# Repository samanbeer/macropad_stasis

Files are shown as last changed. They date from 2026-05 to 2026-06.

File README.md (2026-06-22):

# My MacroPad Project

This is custom 3×3 macropad PCB built with KiCad. It runs with Seeed Studio XIAO RP2040 microcontroller, uses Cherry MX switches and t has RGB lights with SK6812 MINI-E LEDs.

## About This Project

I have done PCB design before, but I wanted to do something more hard like adding MCU, RGB LEDs, and a matrix connection. 
I learned key matrix wiring with diodes, level-shifting logic with the 74AHCT125 processor, PCB routing around an MCU and KiCad in general. 
Also I learned a lot from MarkDown syntax.
I will use this for switching apps, custom scripts in some apps like VsCode for pushing new code to github etc...
The routing was pretty easy, just time consuming but I really enjoed making traces.

## Project Structure

- **[KiCAD_project/](KiCAD_project/)** 
  - `KiCAD_project.kicad_pcb` 
  - `KiCAD_project.kicad_sch` 
  - `KiCAD_project.kicad_pro` 
  - **[output/](KiCAD_project/output/)** 
  - **[OPL_Kicad_Library-master/](KiCAD_project/OPL_Kicad_Library-master/)**
  - **[kicad-libraries-master/](KiCAD_project/kicad-libraries-master/)** 
  - **[kicad_care_package/](KiCAD_project/kicad_care_package/)** 
  - **[KiCAD_project-backups/](KiCAD_project/KiCAD_project-backups/)** 

- **[CAD/](CAD/)** 
  - `3d_PCB.step` 
  - `housing.stl` 
  - `pcb_only.stl` 
  - `With-PCB_for-render.stl` 
  - `Seeed Studio XIAO RP2040.stl` 
  - **[blender/](CAD/blender/)** 

- **[KiCAD_project/My macroPad-bom.csv](KiCAD_project/My%20macroPad-bom.csv)** - BOM

## Design images

### Schematic
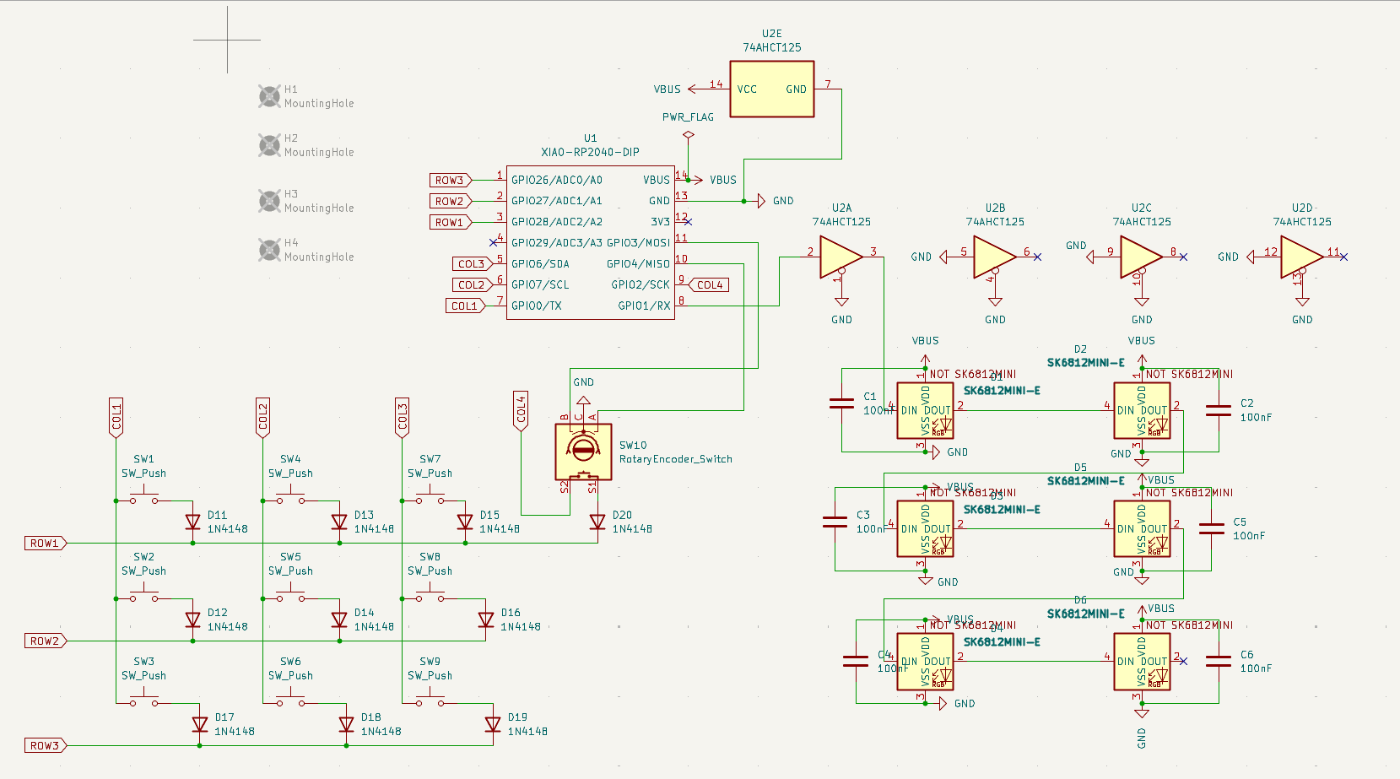
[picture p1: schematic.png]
Schematic


### PCB Layout
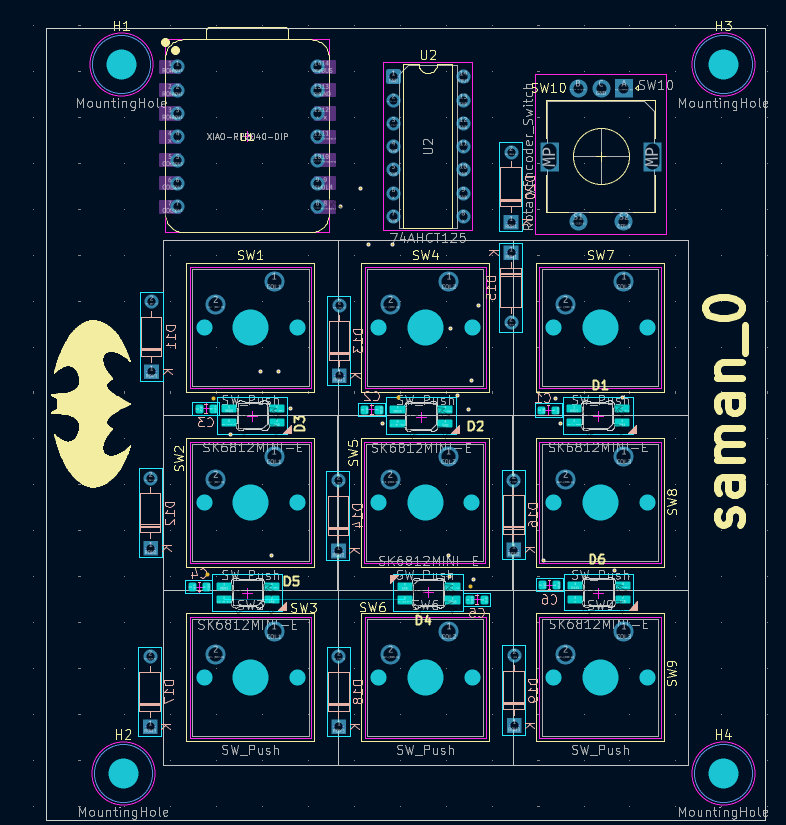
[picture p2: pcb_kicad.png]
PCB Layout


### 3D Renderings

#### Rendered PCB
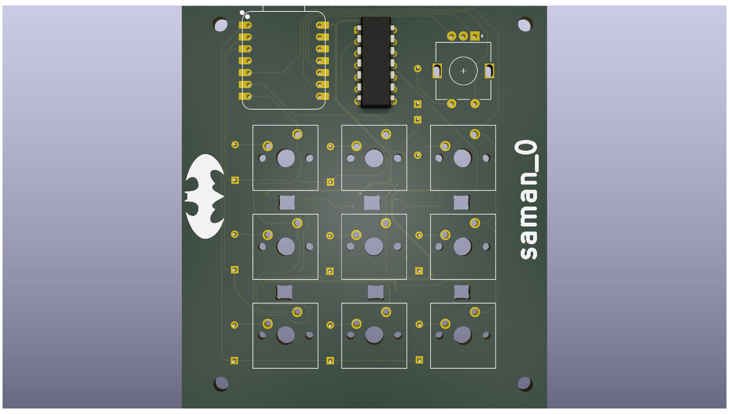
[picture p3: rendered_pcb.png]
Rendered PCB


#### PCB without rendering
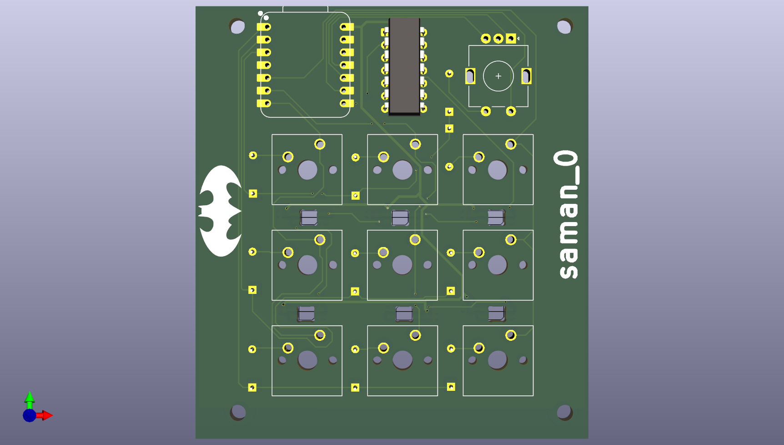
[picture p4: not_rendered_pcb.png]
Non-rendered PCB


#### Rendered Housing for PCB
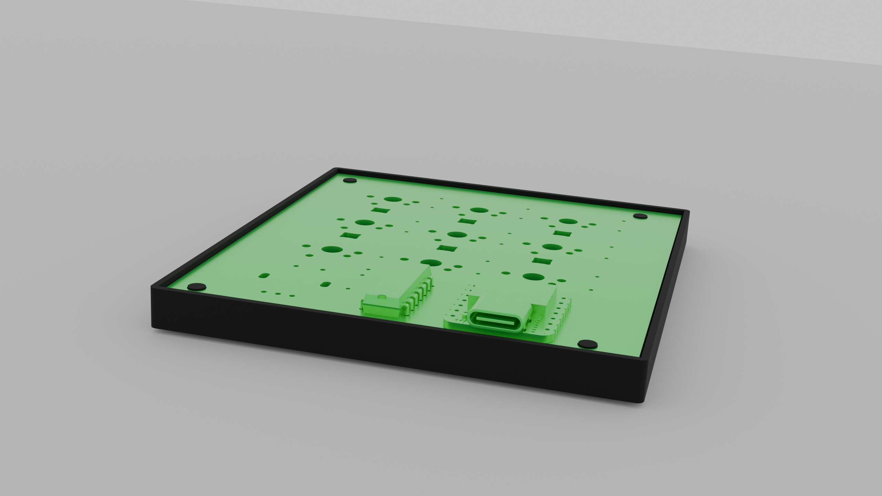
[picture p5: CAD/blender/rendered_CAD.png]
Rendered CAD


#### Housing for PCB (screenshot from fusion360)
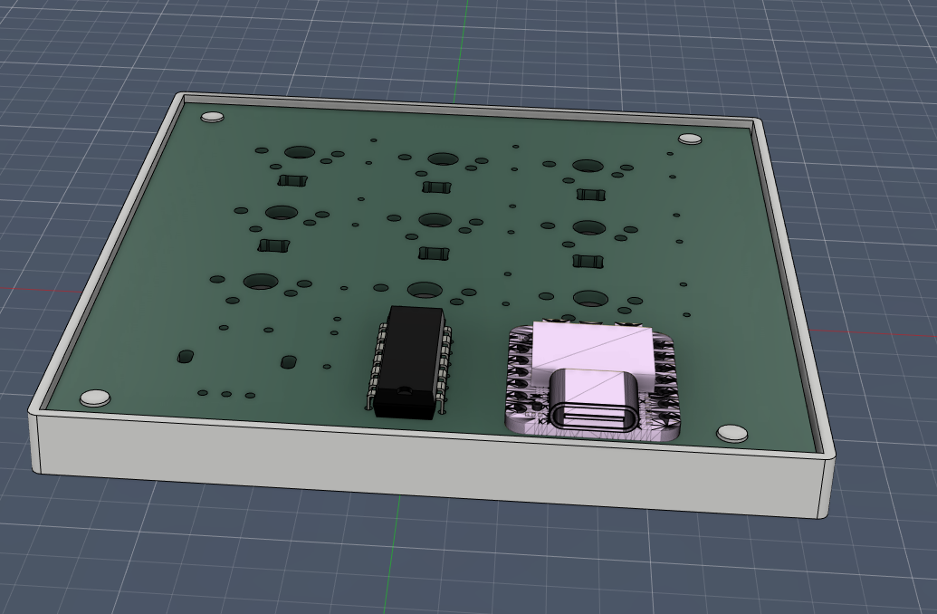
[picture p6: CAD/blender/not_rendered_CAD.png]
Rendered CAD


### Real Photos

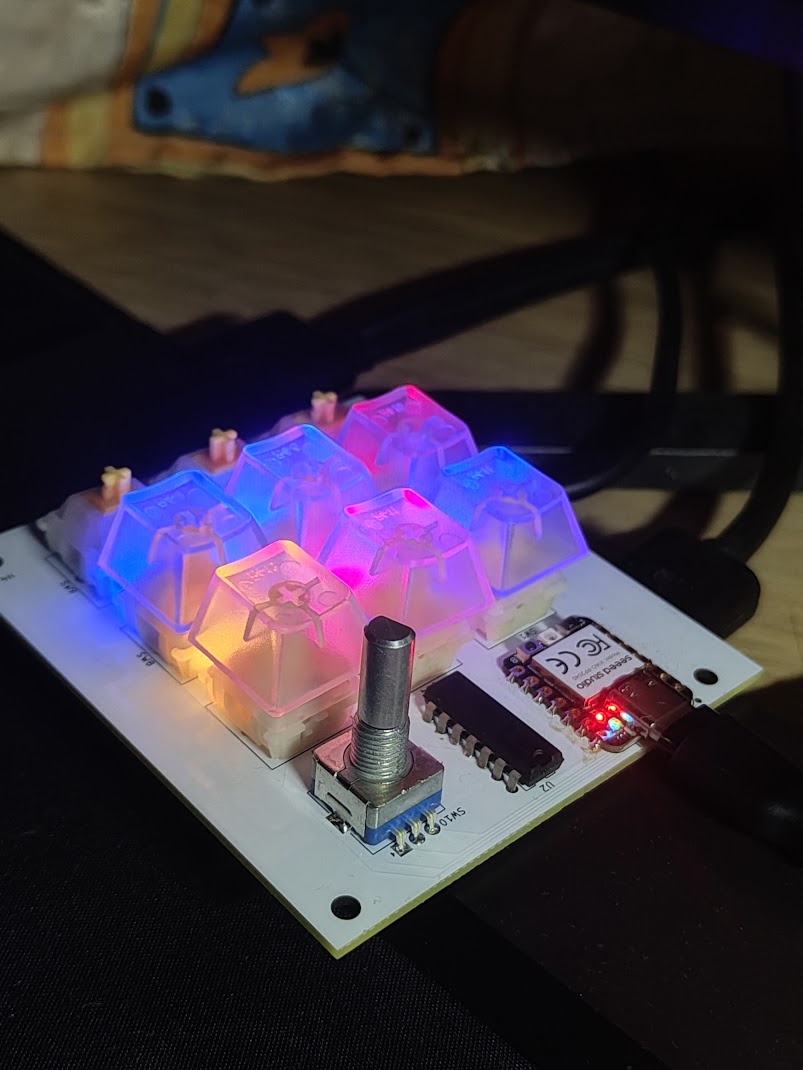
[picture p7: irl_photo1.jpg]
IRL Photo 1


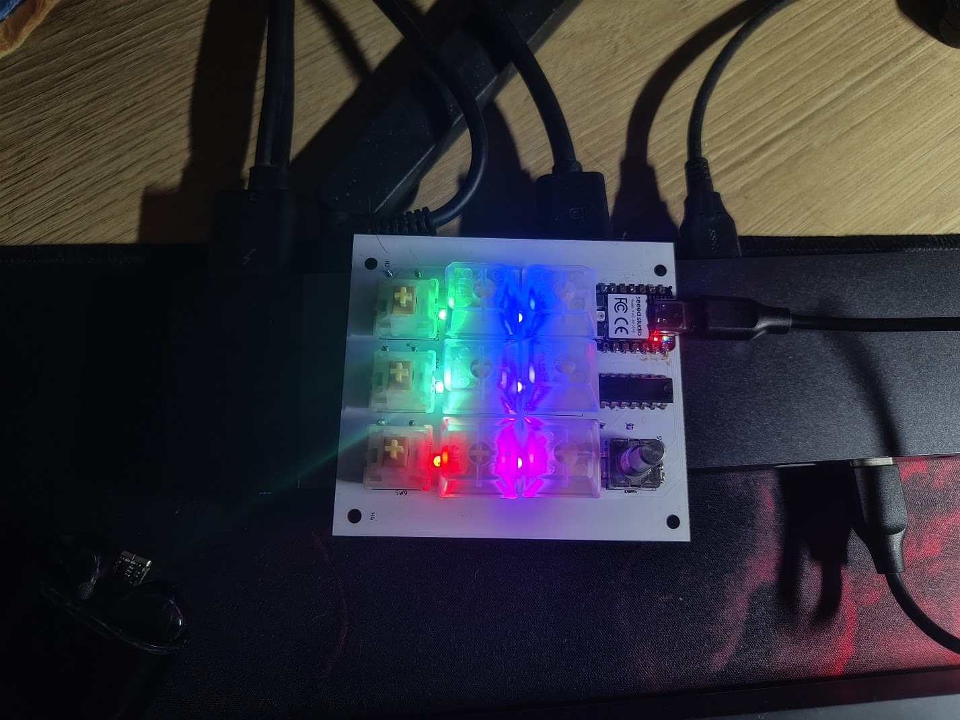
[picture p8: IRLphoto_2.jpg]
IRL Photo 2


Project Link: https://stasis.hackclub.com/dashboard/projects/cmosrdxum001301mxc1tzjn15

## Bill of Materials

| Component | Purpose | Qty | Total | Distributor |
| :--- | :--- | :---: | :---: | :--- |
| PCB | Board to solder all components on | 1 | ~$1.40 | JLCPCB |
| Cherry MX Switches | Key switches | 10 | ~$3.00 | AliExpress |
| Capacitor 0.47 µF 0603 | Prevents LED flicker on voltage spikes | 10 | ~$0.50 | Farnell |
| Diode 1N4148 | Key matrix diodes for preventing ghosting | 10 | ~$2.15 | Farnell |
| SN74AHCT125N | Voltage level-shifter for RGB LED | 1 | ~$0.90 | Farnell |
| SK6812 MINI-E | RGB LED | 1 | ~$2.40 | AliExpress |
| Seeed Studio XIAO RP2040 | Main microcontroller | 1 | ~$4.80 | Farnell |

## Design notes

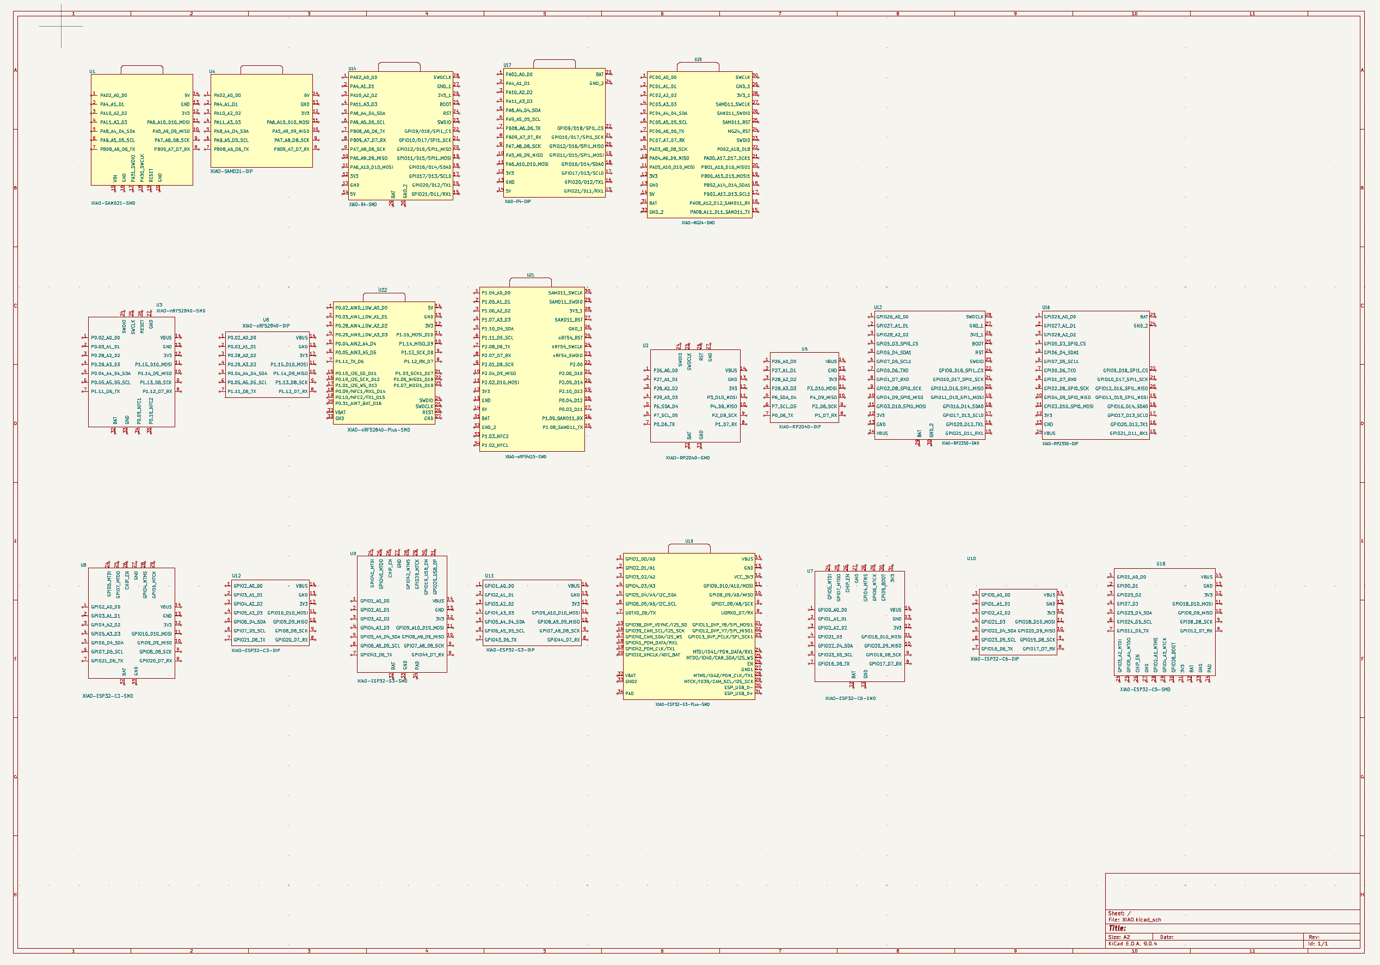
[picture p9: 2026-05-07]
KiCAD_project/OPL_Kicad_Library-master/images/XIAO_Family_1.png

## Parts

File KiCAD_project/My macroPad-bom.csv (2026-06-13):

Component | Purpose | Qty | Unit Cost (USD) | Total | Distributor | Link
PCB | Board to solder all components on | 1 | — | 1.40 | JLCPCB | https://cart.jlcpcb.com/quote
Cherry MX Switches | Key switches | 10 | — | 3.00 | AliExpress | https://www.aliexpress.com/item/1005004341695529.html
Capacitor 0.47 µF 0603 | Decoupling — prevents LED flicker on voltage spikes | 10 | — | 0.50 | Farnell | https://cz.farnell.com/murata/grm188r71e474ka12d/cap-0-47-f-25v-10-x7r-0603/dp/1828901
Diode 1N4148 | Key matrix diodes — prevent ghosting | 10 | — | 2.15 | Farnell | https://cz.farnell.com/multicomp-pro/1n4148/small-signal-diode-single-do-204ah/dp/4245056
SN74AHCT125N | Voltage level-shifter for RGB LED data line | 1 | — | 0.90 | Farnell | https://cz.farnell.com/texas-instruments/sn74ahct125n/logic-bus-buffer-tri-st-qd-14dip/dp/3119387
SK6812 MINI-E | Addressable RGB LED | 1 | — | 2.40 | AliExpress | https://www.aliexpress.com/item/1005008308801366.html
Seeed Studio XIAO RP2040 | Main microcontroller | 1 | — | 4.80 | Farnell | https://cz.farnell.com/seeed-studio/102010428/xiao-board-arm-arduino-board/dp/4060348

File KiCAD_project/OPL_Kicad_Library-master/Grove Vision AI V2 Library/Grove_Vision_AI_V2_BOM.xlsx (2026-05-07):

Layer Jump | Number | Name | Specification | Operating Temperature | MPN Code | Quantity | Base | Plug Position | Process
N | 301010000 | SMD RES 0R-5%-1/16W;0402 |  | -55°C to 155°C | RC0402JR-070RL | 3 | 1 | R29,R30,R39 | SMT1
N | 301010004 | SMD RES 10K-5%-1/16W;0402 |  | -55°C to 155°C | RC0402JR-0710KL | 7 | 1 | R5,R7,R8,R23,R24,R31,R38 | SMT1
N | 301010008 | SMD RES 510K-5%-1/16W;0402 |  | -55°C to 155°C | RC0402JR-07510KL | 1 | 1 | R35 | SMT1
N | 301010456 | SMD RES 100K-1%-1/16W;0402 |  | -55°C to 155°C | RC0402FR-07100KL | 7 | 1 | R6,R10,R11,R16,R32,R33,R37 | SMT1
N | 301010495 | SMD RES;5.1K-1%-1/16W;0402 |  | -55°C to 155°C | RC0402FR-075K1L | 3 | 1 | R2,R3,R36 | SMT1
N | 301010746 | SMD RES 2.2K-1%-1/16W;0402 |  | -55°C to 155°C | RC0402FR-072K2L | 10 | 1 | R1,R4,R13,R14,R15,R19,R20,R21,R22,R40 | SMT1
N | 301011331 | SMD RES 22.1K-1%-1/16W;0402 |  | -55°C to 155°C | RC0402FR-0722K1L | 2 | 1 | R26,R34 | SMT1
N | 302010004 | SMD CAP Ceramic 100nF-16V-10%-X7R;0402 |  | -55°C to 125°C | CC0402KRX7R7BB104 | 18 | 1 | C5,C8,C13,C20,C21,C22,C23,C24,C25,C26,C27,C29,C30,C31,C32,C35,C36,C39 | SMT1
N | 302010006 | SMD CAP Ceramic 10nF-50V-10%-X7R;0402 |  | -55°C to 125°C | CC0402KRX7R9BB103 | 1 | 1 | C3 | SMT1
N | 302010049 | SMD CAP Ceramic 12pF-50V-5%-NPO;0402 |  | -55°C to 125°C | CC0402JRNPO9BN120 | 2 | 1 | C14,C15 | SMT1
N | 302010051 | SMD CAP Ceramic 220nF-16V-10%-X7R;0402 |  | -55°C to 125°C | CC0402KRX7R7BB224 | 1 | 1 | C16 | SMT1
N | 302010407 | SMD CAP Ceramic 4.7uF-10V-10%-X5R;0402 |  | -55°C to 85°C | CC0402KRX5R6BB475 | 7 | 1 | C4,C6,C7,C9,C10,C28,C34 | SMT1
N | 302010519 | SMD CAP Ceramic 10uF-10V-20%-X5R;0402 |  | -55°C to 85°C | CC0402MRX5R6BB106 | 2 | 1 | C11,C37 | SMT1
N | 302013249 | SMD CAP Ceramic 1uF-10V-10%-X5R;0402 |  | -55°C to 85°C | CL05A105KP5NNNC | 5 | 1 | C1,C2,C17,C18,C19 | SMT1
N | 303010544 | SMD Inductor 4.7uH-20%-1.1A;0806 |  | -40°C to 105°C | VLS201610HBX-4R7M-1 | 1 | 1 | L1 | SMT1
N | 303011858 | SMD Inductor 470nH-20%-2.6A;0603 |  | -40°C to 125°C | TFM160808ALC-R47MTAA | 2 | 1 | L2,L3 | SMT1
N | 304011053 | SMD Diode Schottky 40V-1A;SOD-323 |  |  | B5819WS SL | 4 | 1 | D1,D2,D3,D4 | SMT1
N | 304090121 | SMD LED Clear-Green;0402 | As posted |  | BL-HGE37A-AV-TRB | 1 | 1 | LED2 | SMT1
N | 304090746 | SMD LED Clear-Yellow;0402 | As posted |  | 16-213/Y2C-AN2Q1B/3T | 1 | 1 | LED1 | SMT1
N | 305030071 | SMD MOSFET N-CH 20V-500mA;SOT-523 |  |  | CJ1012 | 5 | 1 | Q1,Q2,Q3,Q4,Q5 | SMT1
N | 306011444 | SMD Crystal;24MHz-12pF-10ppm-4P-2.0*1.6*0.5mm |  | -40°C to 85°C | Y2400FE001 | 1 | 1 | X1 | SMT1
N | 310011697 | SMD IC MCU;Dual Cortex-M55 Core(Max 400MHz)-With a 400MHz NPU;WLCSP-65 | L5.58*W2.27mm | -40°C to 85°C | HX6538-A01TWA | 1 | 1 | U1 | SMT1
N | 310032794 | SMD IC PMIC;DCDC Buck-ADJ-2.2MHz-4A;DFN1.5×1.5-6 |  | -40°C to 85°C | SY80004DQD | 2 | 1 | U4,U6 | SMT1
N | 310032813 | SMD IC PMIC;LDO-1.8V-300mA;XTDFN-1*1-4L |  | -40°C to 125°C | SGM2036S-1.8XXDH4G/TR | 1 | 1 | U3 | SMT1
N | 310071431 | SMD IC Interface USB to High Speed TTL;QFN16 | USB to High-Speed Serial Port | -40°C to 85°C | CH343P | 1 | 1 | U2 | SMT1
N | 310091468 | SMD IC Memory;128Mbit-1.8V;SOIC-8 |  | -40°C to 85°C | W25Q128JWSIQ | 1 | 1 | U5 | SMT1
N | 311020009 | SMD Top Button 4N;4P-L4.6*W3.2*H2.5mm |  | -20°C to 70°C | SKRPADE010 | 1 | 1 | RST1 | SMT1
N | 311020518 | SMD Top Button 1.57N;4P-L4.6*W3.2*H2.5mm |  | -30°C to 85°C | SKRPABE010 | 1 | 1 | BOOT1 | SMT1
N | 312030502 | SMD DIGITAL MIC OMNI -26dBFS;OCLGA-4:3.5*2.65*0.94mm |  | -40˚C to 100˚C | MSM261D3526H1CPM | 1 | 1 | MIC1 | SMT1
N | 319015667 | PCB;Grove - Vision AI Module V2 -蓝油白字-4层 | 20*40*1.6mm-ENIG-FR4;Steel mesh code；404012305 |  |  | 1 | 1 |  | SMT1
N | 320011358 | SMD USB TYPE C-W/P;12+4P-8.94*7.35*3.26mm |  | -30°C to 85°C | USB-31C-F-16P-L7.35 | 1 | 1 | J1 | SMT1
N | 320031231 | DIP Black Female Header VERT;1*7P-2.54-5.0mm |  | -40℃ to 105℃ |  | 2 | 1 | P8,P9 | Unit
N | 320060904 | SMD FPC CONN Bottom Contact;15P-1.0mm;L19.9*W6.76*H2.0mm |  | -30°C to 85°C | ST-FPC-W102015-D | 1 | 1 | J2 | SMT1
N | 320090535 | SMD uSD Card Holder;9+4P-L11.25*W6.96*H1.42mm |  | -25°C to 70°C | ST-TF-MR267 | 1 | 1 | J5 | SMT1
N | 320110032 | SMD Grove Female Header-Beige;4P-2.0-90D | 2.0-4PHorizontal Mount with Locking Socket |  | PHS-4A horizontal mount | 1 | 1 | J3 | SMT1

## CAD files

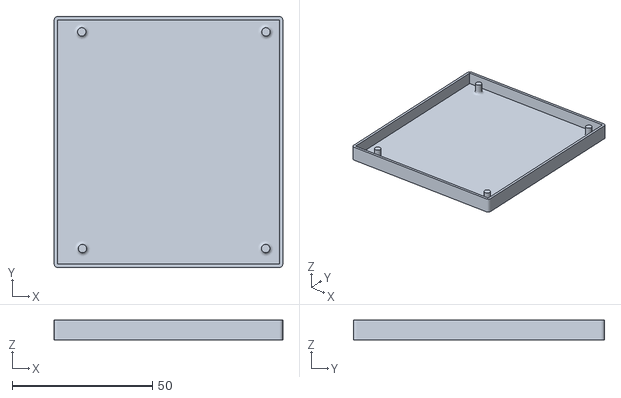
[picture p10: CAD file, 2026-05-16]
CAD/housing.stl
81.4 x 89.4 x 7.00

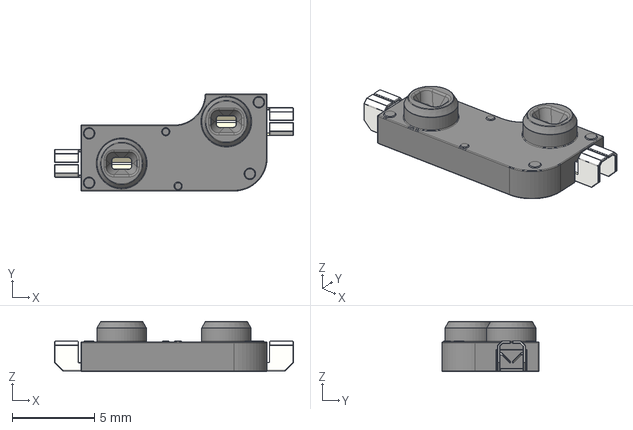
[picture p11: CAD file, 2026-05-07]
KiCAD_project/kicad-libraries-master/models/KailhSocket.stp
14.5 x 5.89 x 3.05 mm

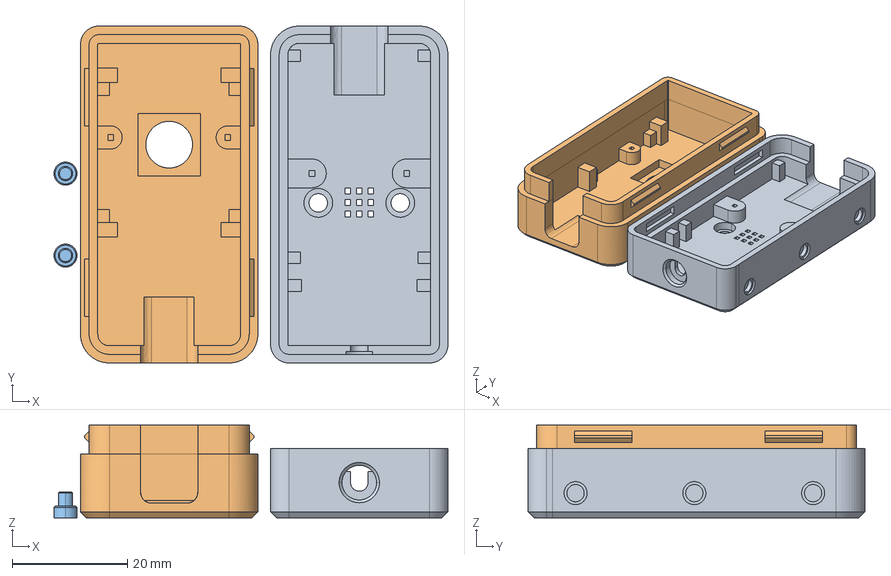
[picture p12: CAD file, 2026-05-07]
KiCAD_project/OPL_Kicad_Library-master/Grove Vision AI V2 Library/himax.stp
68.4 x 58.5 x 16.1 mm

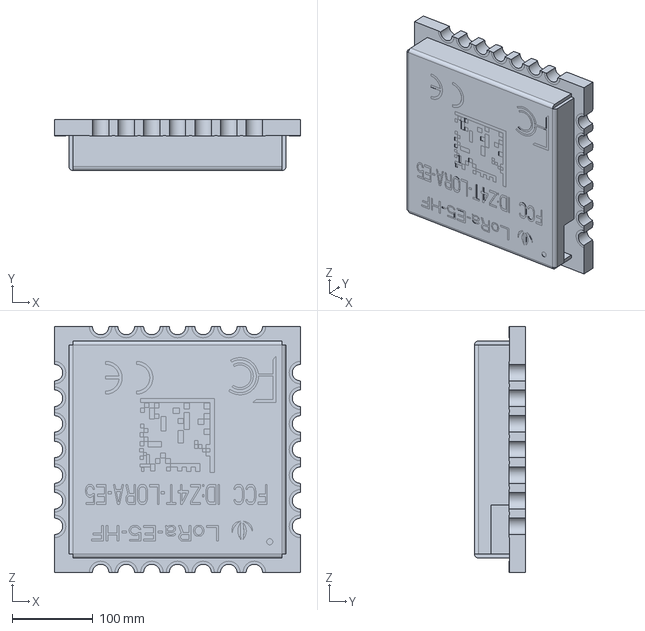
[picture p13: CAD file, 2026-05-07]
KiCAD_project/OPL_Kicad_Library-master/Seeed Studio Wio Series/Wio-E5-LE/LoRa-E5-LE-HF_3D_File.stp
304.8 x 63.8 x 304.8 mm

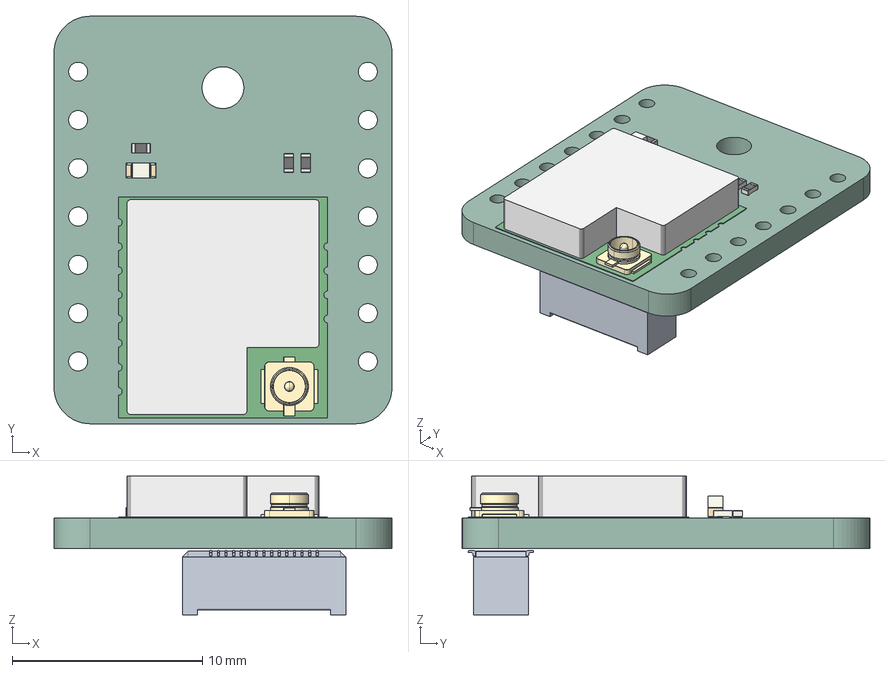
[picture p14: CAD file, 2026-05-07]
KiCAD_project/OPL_Kicad_Library-master/Seeed Studio Wio Series/Wio-SX1262/Wio-SX1262_for_XIAO_3D_file.step
17.8 x 21.4 x 7.30 mm
R_0402_1005Metric x 3
LED_0603_1608Metric
PCB
BF04-30pin-35H
Wio-SX1262 for XIAO V1.0_PCB

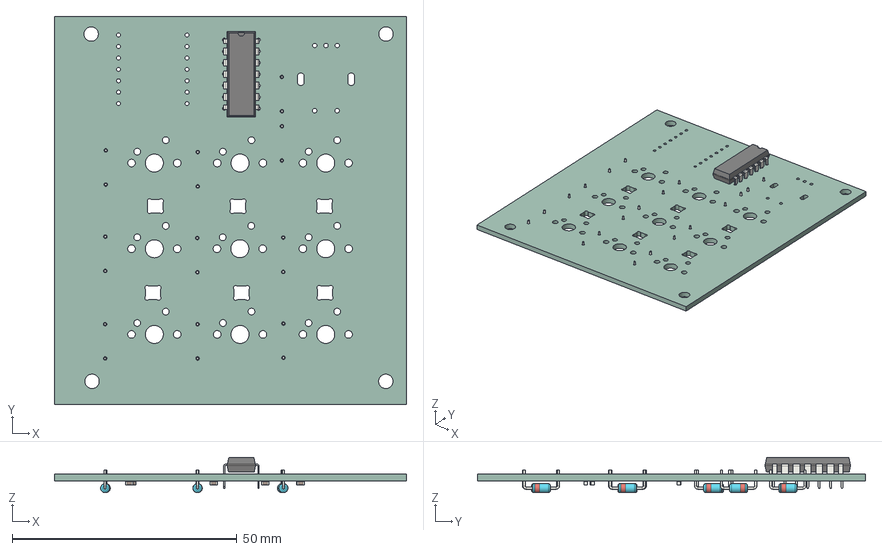
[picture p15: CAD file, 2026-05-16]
CAD/3d_PCB.step
78.4 x 86.2 x 7.87 mm
DIP-14_W7.62mm
C_0603_1608Metric x 6
D_DO-35_SOD27_P7.62mm_Horizontal x 10
KiCAD_project_PCB

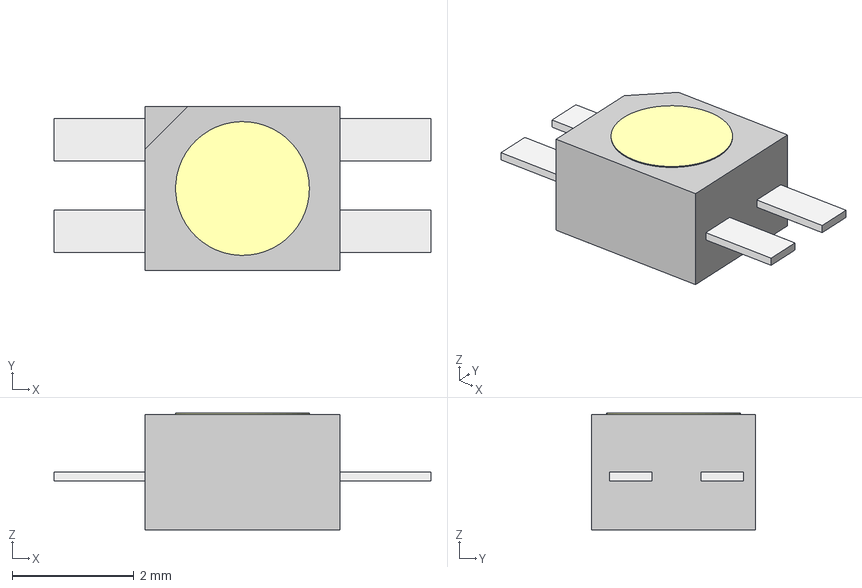
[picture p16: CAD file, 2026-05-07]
KiCAD_project/kicad-libraries-master/models/LTST-A683CEGBW.step
6.20 x 2.70 x 1.92 mm

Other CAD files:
CAD/blender/Untitled.blend
KiCAD_project/OPL_Kicad_Library-master/Grove Vision AI V2 Library/himax.3mf

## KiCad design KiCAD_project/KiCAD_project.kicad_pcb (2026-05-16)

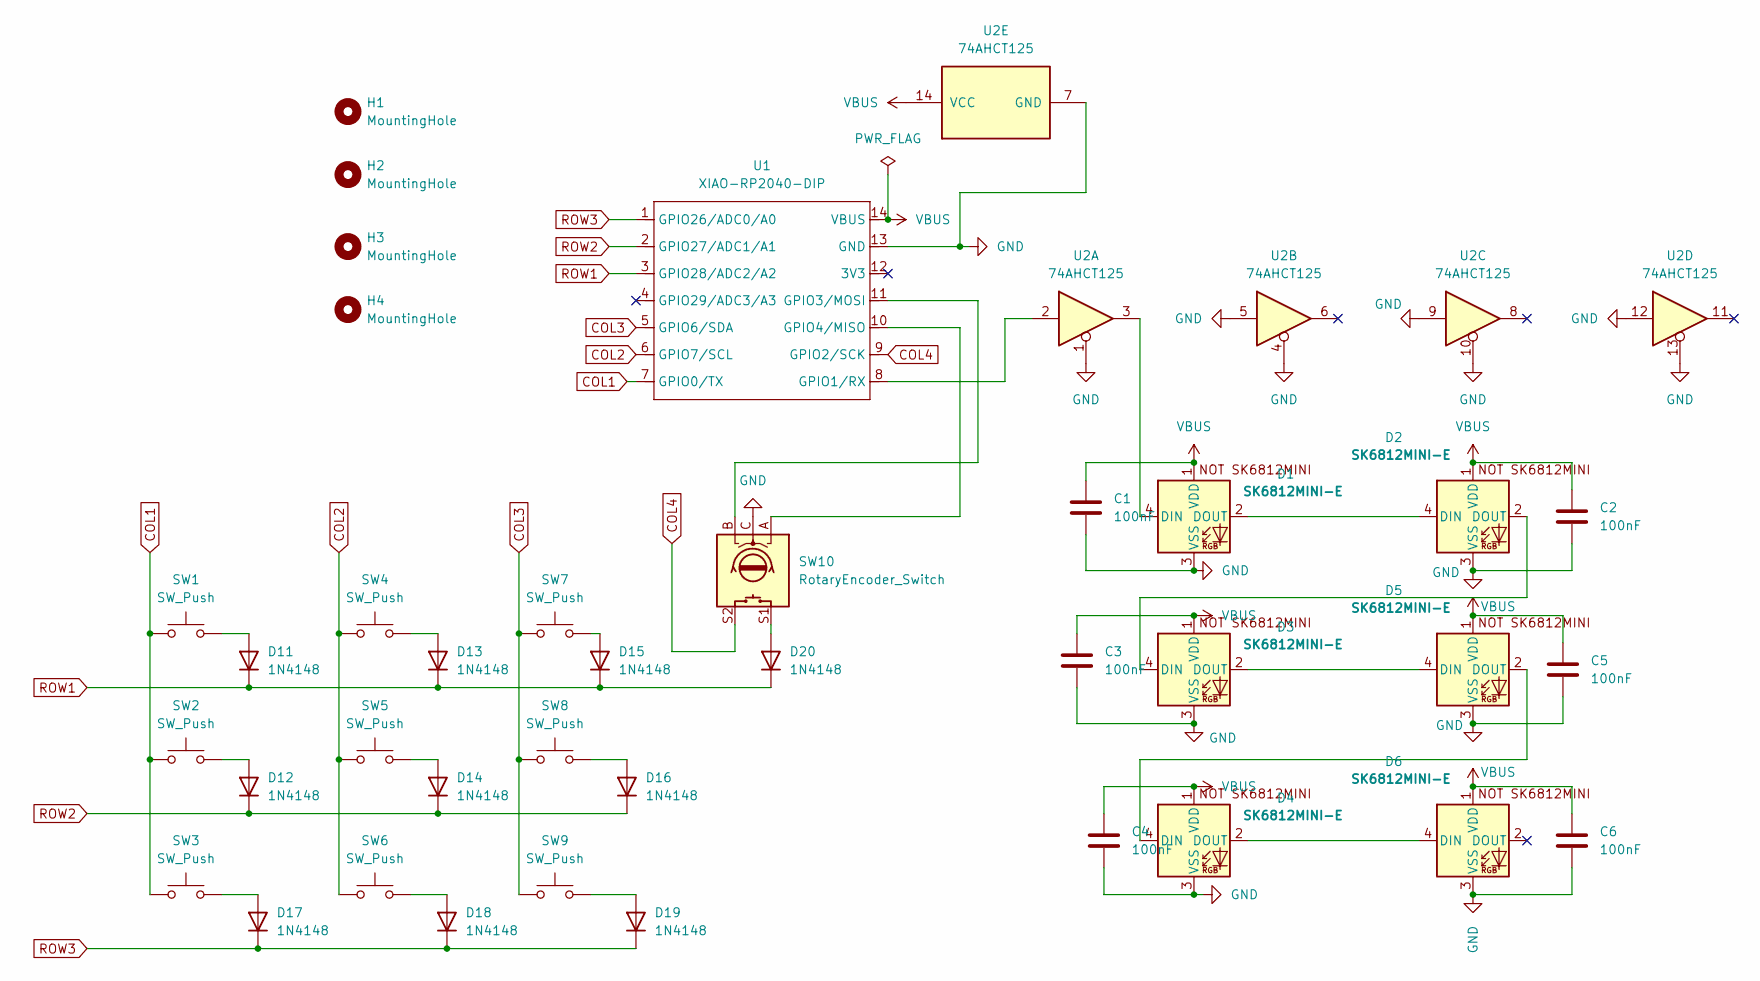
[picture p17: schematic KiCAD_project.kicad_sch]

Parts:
C1, C2, C3, C4, C5, C6: 100nF; C_0603_1608Metric
D1, D2, D3, D4, D5, D6: SK6812MINI-E; SK6812MINI-E_fixed
D11, D12, D13, D14, D15, D16, D17, D18, D19, D20: 1N4148; D_DO-35_SOD27_P7.62mm_Horizontal
H1, H2, H3, H4: MountingHole; MountingHole_3.2mm_M3
SW1, SW2, SW3, SW4, SW5, SW6, SW7, SW8, SW9: SW_Push; SW_Cherry_MX_1.00u_PCB
SW10: RotaryEncoder_Switch; RotaryEncoder_Alps_EC11E-Switch_Vertical_H20mm
U1: XIAO-RP2040-DIP
U2: 74AHCT125; DIP-14_W7.62mm

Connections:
COL1: SW1.1, SW2.1, SW3.1, U1.7 (GPIO0/TX)
COL2: SW4.1, SW5.1, SW6.1, U1.6 (GPIO7/SCL)
COL3: SW7.1, SW8.1, SW9.1, U1.5 (GPIO6/SDA)
COL4: SW10.S2, U1.9 (GPIO2/SCK)
GND: C1.2, C2.2, C3.2, C4.2, C5.2, C6.2, D1.3 (VSS), D2.3 (VSS), D3.3 (VSS), D4.3 (VSS), D5.3 (VSS), D6.3 (VSS), SW10.C, U1.13 (GND), U2.1, U2.4, U2.5, U2.7 (GND), U2.9, U2.10, U2.12, U2.13
unnamed: D1.4 (DIN), U2.3
unnamed: D1.2 (DOUT), D2.4 (DIN)
unnamed: D2.2 (DOUT), D3.4 (DIN)
unnamed: D3.2 (DOUT), D5.4 (DIN)
unnamed: D4.4 (DIN), D5.2 (DOUT)
unnamed: D4.2 (DOUT), D6.4 (DIN)
unnamed: D11.2 (A), SW1.2
unnamed: D12.2 (A), SW2.2
unnamed: D13.2 (A), SW4.2
unnamed: D14.2 (A), SW5.2
unnamed: D15.2 (A), SW7.2
unnamed: D16.2 (A), SW8.2
unnamed: D17.2 (A), SW3.2
unnamed: D18.2 (A), SW6.2
unnamed: D19.2 (A), SW9.2
unnamed: D20.2 (A), SW10.S1
unnamed: U1.8 (GPIO1/RX), U2.2
unnamed: SW10.B, U1.11 (GPIO3/MOSI)
unnamed: SW10.A, U1.10 (GPIO4/MISO)
ROW1: D11.1 (K), D13.1 (K), D15.1 (K), D20.1 (K), U1.3 (GPIO28/ADC2/A2)
ROW2: D12.1 (K), D14.1 (K), D16.1 (K), U1.2 (GPIO27/ADC1/A1)
ROW3: D17.1 (K), D18.1 (K), D19.1 (K), U1.1 (GPIO26/ADC0/A0)
VBUS: C1.1, C2.1, C3.1, C4.1, C5.1, C6.1, D1.1 (VDD), D2.1 (VDD), D3.1 (VDD), D4.1 (VDD), D5.1 (VDD), D6.1 (VDD), U1.14 (VBUS), U2.14 (VCC)

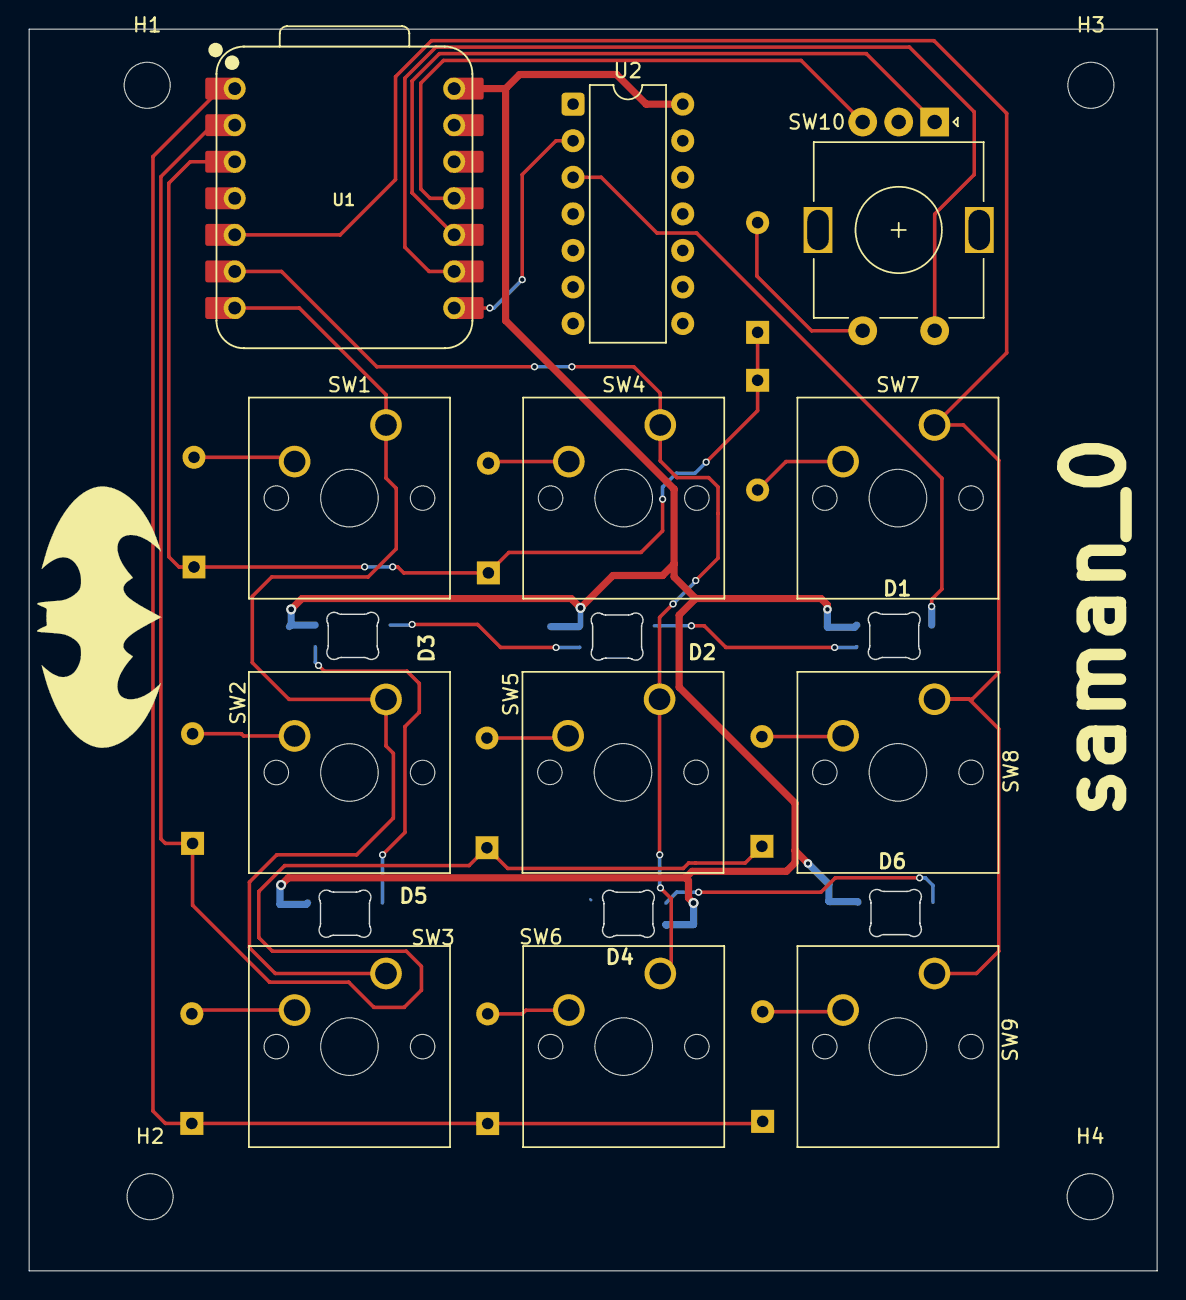
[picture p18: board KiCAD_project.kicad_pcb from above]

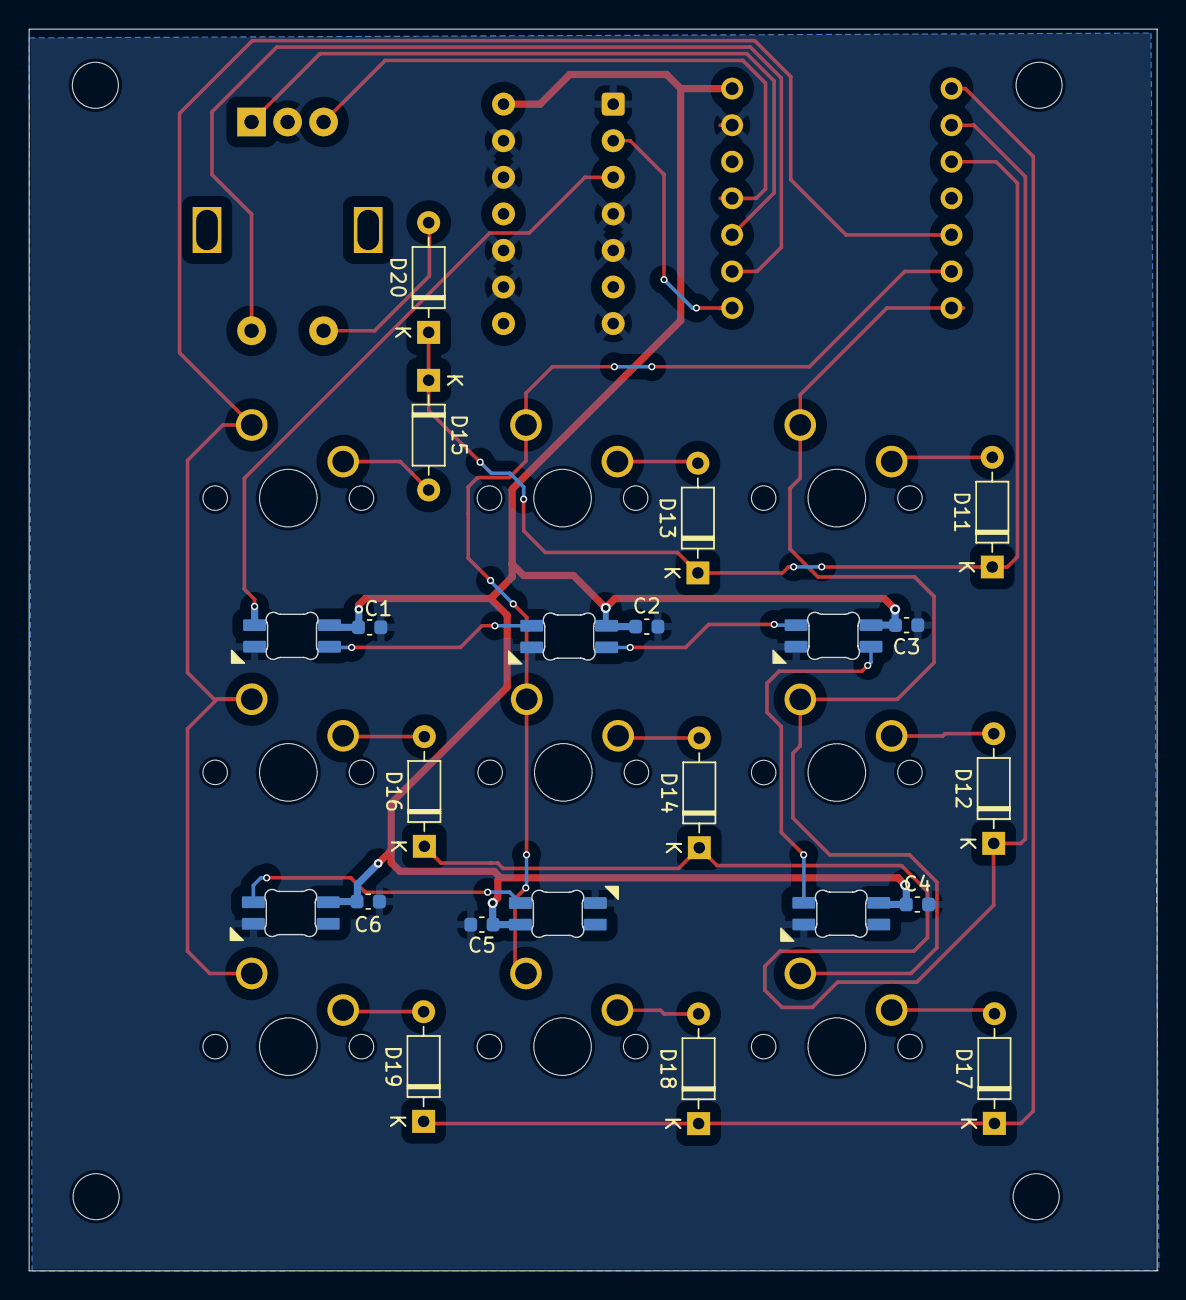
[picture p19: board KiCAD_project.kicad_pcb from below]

Board: 2 copper layers, 78.4 x 86.2 mm, 38 parts (16 on the bottom side), 28 nets.

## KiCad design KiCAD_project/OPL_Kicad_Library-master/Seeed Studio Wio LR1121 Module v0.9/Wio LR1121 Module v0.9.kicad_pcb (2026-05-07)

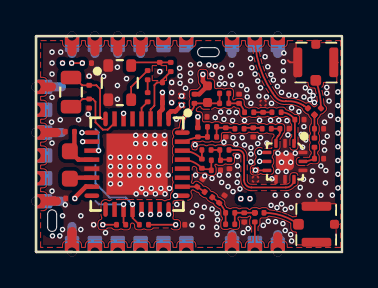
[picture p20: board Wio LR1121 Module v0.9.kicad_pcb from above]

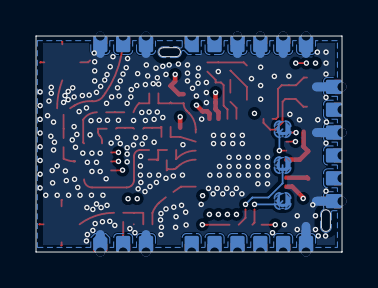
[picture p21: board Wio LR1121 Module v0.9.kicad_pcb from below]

Board: 4 copper layers, 17.0 x 12.0 mm, 69 parts (3 on the bottom side), 47 nets.

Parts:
C1, C2, C3, C4, C5, C6, C7, C8, C9, C11, C12, C13, C14, C15, C18, C19, C20, C22, C24, C25, C26, C27, C28, C29, C30, C31, C32, C33, C34, C35, C36, C37, C38, C39, C40, C41, C42, C43: C0201
FB1: L0201
J1, J2: U-FL4P-SMD-1_7X1_7X1_0MM
L1: L0402
L2, L3, L5, L6, L7, L8, L9, L10, L11, L13: L0201
L12: L0603
OSC1: X4_SMD_2_5X2_0MM
R1, R2, R3, R4, R5, R7, R8, R9: R0201
TP23, TP24, TP25: TP35S_SMD
U1: QFN12_0D5_2X2X0_55MM
U2: QFN32_0D5_5X5MM_EP3P3MM
U3: MODULE24_1D27_17X12MM
X1: X2_SMD_2X1_2MM

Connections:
2.4G_RF: C43.2, U3.2
GND_POWER: C3.2, C4.2, C5.2, C6.2, C7.2, C8.2, C11.2, C12.2, C13.2, C14.2, C15.2, C18.2, C19.2, C22.2, C25.2, C26.2, C28.2, C29.2, C30.2, C31.2, C32.2, C33.2, C35.2, C36.2, C37.2, C38.2, C40.2, C42.2, J1.2, J1.3, J1.4, J2.2, J2.3, J2.4, OSC1.1, OSC1.2, U1.2, U1.7, U1.8, U1.10, U1.12, U1.13, U2.13, U2.33, U3.1, U3.3, U3.9, U3.10, U3.13, U3.15, U3.16, U3.17, U3.18, U3.19, U3.22, U3.24
HP_LF: C1.1, L1.2, L2.1, R1.2, U2.32
LP_LF: C9.1, L6.1, L13.2, U2.31
LR1121_BUSY: U2.25, U3.8
LR1121_DIO8: U2.10, U3.11
LR1121_DIO9_INT: U2.9, U3.12
LR1121_RSTN: C42.1, R7.2, U2.6, U3.14
LR1121_SPI_MISO: U2.21, U3.7
LR1121_SPI_MOSI: U2.22, U3.6
LR1121_SPI_NSS: U2.24, U3.4
LR1121_SPI_SCK: U2.23, U3.5
MCU_DIO5: R3.1, TP23.1, U2.20
MCU_DIO6: R2.1, TP24.1, U2.19
MCU_DIO7: R5.1, TP25.1, U2.11
N18704063: C25.1, U2.7, X1.1
N18704080: C26.1, U2.8, X1.2
N18704168: L12.2, U2.14
N18704177: C31.1, L12.1, U2.12
N18704981: C9.2, C37.1, L6.2, L7.1
N18704990: C1.2, C3.1, L2.2, L3.1
N18705097: C2.1, C4.1, L3.2
N18705182: C38.1, C39.1, L7.2
N18705449: C18.1, C39.2, U1.3
N18705460: C2.2, C5.1, U1.1
N18706098: C20.2, C40.1, C41.1, L9.2
N18706198: C41.2, U1.9
N18706539: C24.1, C29.1, L10.2, L11.1
N18706650: C24.2, C27.1, C30.1, C43.1, L11.2
N18706671: C27.2, J2.1
N18712116: C14.1, L5.1, U1.11
N18712319: C36.1, FB1.2, OSC1.4
N18712325: C34.1, OSC1.3
N18712327: C34.2, R4.1
N18713044: C15.1, L5.2, R8.1, R9.1
N18751757: J1.1, R8.2
RFIO_HF: C28.1, L10.1, U2.26
RFI_N: C22.1, L8.2, L9.1, U2.29
RFI_P: C20.1, L8.1, U2.30
RFSW0_V1: C33.1, R3.2, U1.4
RFSW1_V2: C32.1, R2.2, U1.5
RFSW_VDD: C19.1, R5.2, U1.6
SUBG_RF: R9.2, U3.23
VDD_RF: C11.1, C12.1, C13.1, R7.1, U2.2, U2.15, U3.20, U3.21
VR_PA: C6.1, C7.1, C8.1, L1.1, L13.1, R1.1, U2.1
VTCXO: C35.1, FB1.1, U2.3
XTA: R4.2, U2.4

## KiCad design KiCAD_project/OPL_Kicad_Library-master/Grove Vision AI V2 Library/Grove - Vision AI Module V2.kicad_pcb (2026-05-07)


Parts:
BOOT1: SW_Push; SW_Push_1P1T_NO_Vertical_Wuerth_434133025816
C1, C2, C17, C18, C19: 1uF; C0402
C3: 10nF; C0402
C4, C6, C7, C9, C10, C28, C34: 4.7uF; C0402
C5, C8, C13, C20, C21, C22, C23, C24, C25, C26, C27, C29, C30, C31, C32, C35, C36, C39: 100nF; C0402
C11, C37: 10uF; C0402
C14, C15: 12pF; C0402
C16: 220nF; C0402
D1, D2, D3, D4: B5819WS; D0805_SOD323
D5, D6, D7, D8: DNP; R0402; MPN DF2S6.8FS
J1: USB_C_Receptacle_USB2.0; USB2.0-TYPE-C
J2: Conn_01x15_MountingPin; FPC_DNC_15P_1.0mm
J3: Conn_01x04_MountingPin; 4P-SMD-2.0mm-RIGHT
J5: ST-TF-MR267; SD-TF-MR267; MPN SD-TF-MR267
L1: VLS201610HBX-4R7M-1; L0806
L2, L3: 470nH; L0603
LED1: Yellow; LED0402
LED2: Green; LED0402
M1: XIAO Connector/DNP; XIAO_Socket
MIC1: MSM261D3526H1CPM; MIC6P-3.5X2.65X0.94MM
Q1, Q2, Q3, Q4, Q5: CJ1012; SOT523
R1, R4, R13, R14, R15, R19, R20, R21, R22, R40: 2.2k; R0402
R2, R3, R36: 5.1k; R0402
R5, R7, R23, R24: 10k; R0402
R6, R16, R32, R33: 100K; R0402; Power Rating 1%; MPN RC0402JR-074K7L
R8, R31, R38: 10K; R0402; Power Rating 5%; MPN RC0402JR-074K7L
R9, R12, R17, R18, R25, R27, R28: DNP; R0402
R10, R11, R37: 100k; R0402
R26, R34: 22K; R0402; Power Rating 1%; MPN RC0402JR-074K7L
R29, R30, R39: 0R; R0402
R35: 510k; R0402
RST1: SW_Push; SW_Push_1P1T_NO_Vertical_Wuerth_434133025816
TP1, TP2, TP3: Test Point; TP-D35MIL; Part Type Test Point
U1: HX6538; WLCSP65_5.6x2.3x0.56mm
U2: CH343P; QFN-16-EP_3x3mm_P0.5mm_EP1x1mm
U3: WR0331-18FF4R; X2SON-4
U4, U6: SY80004DQD; DFN6-0.5-1.5X1.5X0.65MM; MPN SY80004DQD
U5: W25Q128JWSIQ; SOIC-8_5.23x5.23mm_P1.27mm
X1: 24MHz; 4P2016

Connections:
1V8: C13.1, C19.2, C20.1, C21.1, C28.1, C29.2, Q1.1 (G), Q2.1 (G), R5.1, R21.2, R22.2, R25.1, TP2.1 (T), U1.F3 (VDDIO_SIF1), U1.G3 (VDDA_RX), U1.H5 (VDDA_TX), U1.L2 (VDDIO_SIF2), U3.1 (OUT), U5.8 (VCC)
/0V9: C4.1, C7.1, L1.2, U1.L4 (DCDC_OUT)
BOOTOPT0: D3.1 (K), R11.1, U1.F4 (BOOT_OPT)
GND: C1.2, C2.2, C3.2, C4.2, C5.2, C6.2, C7.2, C8.1, C9.2, C10.2, C11.1, C13.2, C14.2, C15.1, C17.2, C18.2, C19.1, C20.2, C21.2, C22.2, C23.2, C24.1, C25.1, C26.2, C27.1, C28.2, C29.1, C30.1, C31.2, C34.2, C35.1, C37.1, C39.1, D5.1, D6.1, D7.1, D8.1, J1.A1_B1_A12_B12 (GND), J1.S1 (SHIELD), J2.1, J2.4, J2.7, J2.10, J2.MP (MountPin), J3.4, J3.MP (MountPin), J5.S1 (SHD1), J5.S2 (SHD2), J5.S3 (SHD3), J5.S4 (SHD4), J5.T6 (VSS), LED2.1 (K), M1.13 (GND), MIC1.4 (GND), MIC1.5 (L/R), MIC1.6 (GND), Q3.2 (S), R2.2, R3.2, R10.2, R11.2, R23.2, R26.1, R34.1, R37.2, RST1.2, TP3.1 (T), U1.C5 (GND1), U1.G4 (GND2), U1.H3 (GND3), U1.L3 (GND4), U1.M2 (GND5), U1.M4 (GND6), U2.2 (GND), U2.17 (EPAD), U3.2 (GND), U3.T (GND), U4.4 (GND), U5.4 (GND), U6.4 (GND), X1.2 (1), X1.4 (3)
GROVE_5V_IN: C18.1, C34.1, C35.2, J3.3, R14.1, R15.1, R31.2, R32.2, U6.6 (IN)
I2CS0_SCL/5V: J3.1, Q4.3 (D), R14.2
I2CS0_SDA/5V: J3.2, Q5.3 (D), R15.2
M_3V3_SCL: J2.13, Q1.3 (D), R19.2
M_3V3_SDA: J2.14, Q2.3 (D), R20.2
unnamed: BOOT1.2, R4.2
unnamed: D1.2 (A), R36.2
unnamed: C9.1, C10.1, C27.2, D2.1 (K), D4.1 (K), R6.2, R8.2, U4.6 (IN)
unnamed: BOOT1.1, D3.2 (A), R36.1
unnamed: J1.A5 (CC1), R2.1
unnamed: J1.B5 (CC2), R3.1
unnamed: LED1.2 (A), R38.1
unnamed: LED1.1 (K), Q3.3 (D)
unnamed: LED2.2 (A), R24.2
unnamed: M1.12 (3V3), R39.2
unnamed: MIC1.2 (CLK), R29.1
unnamed: MIC1.3 (DATA), R30.1
unnamed: Q3.1 (G), R37.1, R40.2
unnamed: R10.1, U1.E4 (TEST_MODE)
unnamed: L1.1, U1.L5 (VX1)
unnamed: C14.1, R35.1, U1.G2 (XTAL_24M_I), X1.3 (4)
unnamed: C15.2, R35.2, U1.F1 (XTAL_24M_O), X1.1 (2)
unnamed: C16.2, U2.13 (RTS)
unnamed: R8.1, U4.1 (EN)
unnamed: C32.1, R16.1, R26.2, U4.3 (FB)
unnamed: L2.1, U4.5 (LX)
unnamed: R6.1, U4.2 (PG)
unnamed: R31.1, U6.1 (EN)
unnamed: C36.1, R33.1, R34.2, U6.3 (FB)
unnamed: L3.1, U6.5 (LX)
unnamed: R32.1, U6.2 (PG)
PA0/3V3: M1.1 (D0/A0), U1.D4 (PA0)
PA1/VMUTE/3V3: J2.11, U1.C4 (PA1)
PA2/I2CS0_SCL/3V3: M1.6 (D5/SCL), Q4.2 (S), R1.1, R17.2, U1.A4 (PA2)
PA3/I2CS0_SDA/3V3: M1.5 (D4/SDA), Q5.2 (S), R13.1, R18.2, U1.B4 (PA3)
PB0/RX0/3V3: U1.A5 (PB0), U2.4 (TXD)
PB1/TX0/3V3: U1.B5 (PB1), U2.5 (RXD)
PB2/SSPIM_DO/3V3: D7.2, J5.T3 (CMD), M1.11 (D10/MOSI), R12.2, U1.N5 (PB2)
PB3/SSPIM_DI/3V3: D5.2, J5.T7 (DAT0), M1.10 (D9/MISO), R9.2, U1.M3 (PB3)
PB4/SSPIM_SCLK/3V3: D6.2, J5.T5 (CLOCK), M1.9 (D8/SCK), R27.2, U1.N4 (PB4)
PB5/SSPIM_~CS/3V3: D8.2, J5.T2 (CD/DAT3), R28.2, U1.N3 (PB5)
PB6/UART1_RX/3V3: M1.7 (D6/TX), U1.N1 (PB6)
PB7/UART1_TX/3V3: M1.8 (D7/RX/SS), U1.M1 (PB7)
PB8/3V3: M1.3 (D2/A2), U1.L1 (PB8)
PB9/PDM_CLK/3V3: R29.2, U1.F5 (PB9)
PB10/PDM_DATA0/3V3: R30.2, U1.G5 (PB10)
PB11/3V3: M1.2 (D1/A1), U1.J3 (PB11)
QSPI_CLK: U1.C2 (QSPI_CLK), U5.6 (CLK)
QSPI_CS: R5.2, U1.B2 (QSPI_CS), U5.1 (~CS)
QSPI_D0: U1.B1 (QSPI_DIO0), U5.5 (DI(IO0))
QSPI_D1: U1.D3 (QSPI_DIO1), U5.2 (DO(IO1))
QSPI_D2: U1.A1 (QSPI_DIO2), U5.3 (IO2)
QSPI_D3: U1.E3 (QSPI_DIO3), U5.7 (IO3)
RST: C3.1, C16.1, M1.4 (D3/A3), R7.1, RST1.1, U1.E5 (RESETN)
RX_CK_N: J2.8, U1.E2 (RX_CKN)
RX_CK_P: J2.9, U1.F2 (RX_CKP)
RX_D0_N: J2.2, U1.D2 (RX_DN0)
RX_D0_P: J2.3, U1.C1 (RX_DP0)
RX_D1_N: J2.5, U1.D1 (RX_DN1)
RX_D1_P: J2.6, U1.E1 (RX_DP1)
SEN_D1/SD~INSERT: J5.G1 (SWITCH), R25.2, U1.G1 (SEN_D1)
SEN_I2CM_SCL: Q1.2 (S), R21.1, U1.A3 (SEN_I2CM_SCL)
SEN_I2CM_SDA: Q2.2 (S), R22.1, U1.B3 (SEN_I2CM_SDA)
UD+: J1.A6 (D+), J1.B6 (D+), U2.7 (D+)
UD-: J1.A7 (D-), J1.B7 (D-), U2.8 (D-)
USER_LED/1V8: R40.1, U1.K2 (SEN_D2)
USR_BTN/1V8: D1.1 (K), R23.1, U1.H1 (SEN_D0)
V33IO: C2.1, C31.1, U2.1 (VIO), U2.6 (V3)
VBUS: C1.1, C30.2, D4.2 (A), J1.A4_B4_A9_B9 (VBUS), U2.3 (VDD5), U2.9 (VBUS)
VCC_3V3: C5.1, C6.1, C8.2, C11.2, C17.1, C22.1, C23.1, C24.2, C25.2, C26.1, C32.2, C36.2, C37.2, C39.2, J2.15, J5.T4 (VDD), L2.2, L3.2, MIC1.1 (VDD), Q4.1 (G), Q5.1 (G), R1.2, R4.1, R7.2, R9.1, R12.1, R13.2, R16.2, R17.1, R18.1, R19.1, R20.1, R24.1, R27.1, R28.1, R33.2, R38.2, R39.1, TP1.1 (T), U1.D5 (VDDIO_AON), U1.M5 (VDDA_DCDC), U1.N2 (VDDIO_PIF), U3.3 (EN), U3.4 (IN)
VMAIN: D2.2 (A), M1.14 (VUSB)

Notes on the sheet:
MIPI CSI
AON 3V3
MIPI DSI
PIF 3V3
SIF only 1V8
Imax=600mA
23/11/14
Grove - Vision AI Module V2
JN.FUONG



Board: 4 copper layers, 40.0 x 20.0 mm, 112 parts (31 on the bottom side), 75 nets.

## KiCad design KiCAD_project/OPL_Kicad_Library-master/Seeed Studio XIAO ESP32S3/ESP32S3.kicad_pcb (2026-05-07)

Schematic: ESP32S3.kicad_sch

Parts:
ANT1: U.FL-R-SMT-1; U-FL3P-SMD-2.6X2.6X1.0MM
BAT0: VBAT; TP-80X40MIL
C1, C2, C17, C20: DNP; C0201
C3, C9, C13, C16: 2.2uF; C0201
C4, C5, C6: 4.7uF; C0201
C7, C8, C28: 10pF; C0201
C10, C21, C25, C26: 1uF; C0201
C11, C14, C15, C19, C22, C23, C29, C30: 100nF; C0201
C12: 10nF; C0201
C18: 1pF; C0201
CHG0: RED; LED-0402
D2: LMBR4010BST5G; DFN1006-2L
D3: Yellow; LED-0402
GND0: GND; TP-80X40MIL
J1, J2: DNP; H7-HALF-HOLE-2.54
J3: DF40C-30DP-0.4V(51); BTB30-0.4-7.52X2.97X1.14
K1, K2: SKTAAAE010/311021459; SW4-SMD-2.8-2.6X1.6X0.53MM
L1: 2nH; L0201
L2: 3.3nH; L0201
L3: DNP; L0201
L4: 470nH; L0603
Q1: LP0404N3T5G; PMOS_1.0_0.6_0.35MM
R1, R2: 5.1K; R0201
R3, R4: 22R; R0201
R5: 0R; R0201
R6: 499R; R0201
R7, R8, R11: 10K; R0201
R9: 100K; C0201
R10: 220K; R0201
R13: 249K; R0201
R15: 1.5K; R0201
TP1, TP2, TP3, TP4, TP5, TP6, TP7, TP8: TEST-POINT'4545'; TP-D45MIL
U1: ESP32-S3R8; QFN56G-0.4-7X7MM
U3: SGM6029CYG/TR; BGA6-0.35-0.745X10.95X0.4MM
U4: SGM40567-4.2XG/TR; WLCSP-0.4-0.92X1.16X0.4MM
U5: GD25Q64ENIGR; USON8-0.8-4X3MM
USB0: UBF31-0171; USB2.0-TYPE-C
X1: 40MHz/306011364; X4-SMD-1.6X1.2X0.35MM

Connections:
D0/A0: J2.1, J2.13 (1), U1.6 (GPIO1)
D1/A1: J2.2, J2.14 (2), U1.7 (GPIO2)
D2/A2: J2.3, J2.15 (3), J3.2, U1.8 (GPIO3)
D3/A3: J2.4, J2.16 (4), U1.9 (GPIO4)
D4/I2C_SDA: J2.5, J2.17 (5), U1.10 (GPIO5)
D5/I2C_SCL: J2.6, J2.18 (6), U1.11 (GPIO6)
D6/TX: J2.7, J2.19 (7), R6.2
D7/RX: J1.1, J1.13 (1), U1.50 (U0RXD)
D8/A8/SCK: J1.2, J1.14 (2), J3.3, U1.12 (GPIO7)
D9/A9/MISO: J1.3, J1.15 (3), J3.4, U1.13 (GPIO8)
D10/A10/MOSI: J1.4, J1.16 (4), J3.5, U1.14 (GPIO9)
EN: C21.2, K1.1 (A0), K1.3 (A1), R8.1, TP6.T, U1.4 (CHIP_PU)
ESP_USB_D+: C1.2, R4.2, TP8.T, U1.26 (GPIO20)
ESP_USB_D-: C2.2, R3.2, TP7.T, U1.25 (GPIO19)
GND: ANT1.GND1, ANT1.GND2, C1.1, C2.1, C3.2, C4.2, C5.1, C6.1, C7.2, C8.1, C9.1, C10.2, C11.1, C12.1, C13.1, C14.1, C15.1, C16.1, C17.1, C18.1, C19.1, C20.1, C21.1, C22.1, C23.2, C25.2, C26.2, C28.1, C29.1, C30.1, GND0.1, J1.6, J1.18 (6), J3.1, J3.17, J3.28, J3.29, J3.31, J3.33, J3.34, K1.2 (B0), K1.4 (B1), K2.2 (B0), K2.4 (B1), R1.1, R2.2, R9.1, R10.1, R13.1, TP1.T, U1.57 (GND), U3.A1 (GND), U4.B1 (F), U4.C2 (GND), U5.4 (GND), USB0.A1_B12 (A1/B12/GND), USB0.B1_A12 (B1/A12/GND), USB0.S1, USB0.S2, USB0.S3, USB0.S4, USB0.S5 (S1), USB0.S6 (S2), X1.2 (GND), X1.4 (GND@1)
GND5: L4.1, U3.B2 (SW)
GND6: R13.2, U3.C1 (MODE)
GPIO0: C28.2, K2.1 (A0), K2.3 (A1), R7.1, U1.5 (GPIO0)
IO10/XMCLK: J3.6, U1.15 (GPIO10)
IO11/DVP_Y8: J3.7, U1.16 (GPIO11)
IO12/DVP_Y7: J3.8, U1.17 (GPIO12)
IO13/DVP_PCLK: J3.9, U1.18 (GPIO13)
IO14/DVP_Y6: J3.10, U1.19 (GPIO14)
IO15/DVP_Y2: J3.11, U1.21 (XTAL_32K_P)
IO16/DVP_Y5: J3.12, U1.22 (XTAL_32K_N)
IO17/DVP_Y3: J3.13, U1.23 (GPIO17)
IO18/DVP_Y4: J3.14, U1.24 (GPIO18)
IO21/USER_LED: D3.-, J3.16, U1.27 (GPIO21)
IO38/DVP_VSYNC: J3.23, U1.43 (GPIO38)
IO47/DVP_HREF: J3.22, U1.37 (SPICLK_P)
IO48/DVP_Y9: J3.21, U1.36 (SPICLK_N)
MTCK/IO39/CAM_SCL: J3.24, TP5.T, U1.44 (MTCK)
MTDI/IO41/PDM_DATA: J3.26, TP3.T, U1.47 (MTDI)
MTDO/IO40/CAM_SDA: J3.25, TP4.T, U1.45 (MTDO)
MTMS/IO42/PDM_CLK: J3.27, TP2.T, U1.48 (MTMS)
unnamed: R5.1, U1.54 (XTAL_P)
unnamed: C7.1, R5.2, X1.3 (X2)
unnamed: C8.2, U1.53 (XTAL_N), X1.1 (X1)
unnamed: ANT1.D, C17.2, L2.1, L3.2
unnamed: R2.1, USB0.B5 (B5/CC2)
unnamed: C15.2, L1.2, U1.2 (VDD3P3@1), U1.3 (VDD3P3@2)
unnamed: R1.2, USB0.A5 (A5/CC1)
unnamed: C18.2, L2.2, U1.1 (LNA_IN)
unnamed: CHG0.-, U4.B2 (NCHG)
unnamed: R6.1, U1.49 (U0TXD)
unnamed: R10.2, U4.C1 (IREF)
unnamed: CHG0.+, R11.2
unnamed: D3.+, R15.1
unnamed: C20.2, L3.1
SPICLK: U1.33 (SPICLK), U5.6 (CLK)
SPICS0: U1.32 (SPICS0), U5.1 (/CS)
SPID: U1.35 (SPID), U5.5 (DIO)
SPIHD: U1.30 (SPIHD), U5.7 (/HOLD)
SPIQ: U1.34 (SPIQ), U5.2 (DO)
SPIWP: U1.31 (SPIWP), U5.3 (/WP)
USB_D+: R4.1, USB0.A6 (A6/DP1), USB0.B6 (B6/DP2)
USB_D-: R3.1, USB0.A7 (A7/DN1), USB0.B7 (B7/DN2)
VBAT: BAT0.1, C26.1, Q1.1 (D), U4.A1 (BAT)
VBUS: C10.1, C25.1, D2.+, J1.7, J1.19 (7), Q1.2 (G), R9.2, R11.1, U4.A2 (VIN), USB0.A4_B9 (A4/B9/VBUS), USB0.B4_A9 (B4/A9/VBUS)
VCC_3V3: C5.2, C6.2, C9.2, C11.2, C12.2, C13.2, C14.2, C16.2, C19.2, C23.1, C29.2, J1.5, J1.17 (5), J3.18, J3.19, L1.1, L4.2, R7.2, R8.2, R15.2, U1.20 (VDD3P3_RTC), U1.46 (VDD3P3_CPU), U1.55 (VDDA@1), U1.56 (VDDA@2), U3.A2 (VOS)
VDD_SPI: C22.2, U1.29 (VDD_SPI), U5.8 (VCC)
VIN: C3.1, C4.1, C30.2, D2.-, J3.15, J3.30, Q1.3 (S), U3.B1 (VIN), U3.C2 (EN)

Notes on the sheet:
IO40
IO39
Π Type Impedance Matching
2.Adjust C30 and C16 inward
D0/A0/Qt1
DVP_Y7
Li Battery
IO5
External Flash
Optimize the distance from the positioning hole of the shield to the pads on both sides
DVP_Y3
D10/A10/Qt9/MOSI
0.3A/Pin
2023/1/4
LC Filter
IO1
D1/A1/Qt2
CAM
IO12
ESP32-S3
USB D+
Layout note： Bottom
D9/A9/Qt8/MISO
IO42
S3 IO20/D+
PDM_CLK
LCD
XIAO Header
v1.1
IO47
IO48
IO4
Camera
DVP_Y6
Internal PSRAM
IO21
IO11
BOOT
CAM_SCL
IO10



Board: 2 copper layers, 17.8 x 21.1 mm, 72 parts (11 on the bottom side), 62 nets.

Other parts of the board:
U$7: LOGO-SEEED-NEW-0.94X8.4MM

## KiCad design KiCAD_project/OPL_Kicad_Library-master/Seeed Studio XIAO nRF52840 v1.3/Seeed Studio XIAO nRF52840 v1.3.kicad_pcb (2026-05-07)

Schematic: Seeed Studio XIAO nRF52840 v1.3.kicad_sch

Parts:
ANT1: ANTENNA-AN3216; ANT-SMD3P-3.2X1.6X1.04MM
BAT0: TEST-POINT'4080'; TP-80X40MIL
C1, C5, C8, C24, C34: 100nF; C0201
C2, C7: 10pF; C0201
C3, C4, C6, C9, C22, C25, C29, C30, C39, C41, C42: 2.2uF; C0201
C10: 1nF; C0402
C11: 1pF; C0201
C31: 820pF; C0201
C32, C33: 15pF; C0201
C35: 100pF; C0201
C36: 0.8pF; C0201
C37: 0.5pF; C0201
C38: 4.7nH; L0201
C40: DNP; C0201
CHG0: RED; LED-0402
D1: DIODE'0603'; SOD-523
GND0: GND; TP-80X40MIL
J1, J2: DNP; H7-HALF-HOLE-2.54
K1: BUTTON-4P; SW4-SMD-2.8-2.6X1.6X0.53MM
L3: 10uH; L0603
MIC1: MSM261D3526H1CPM; MIC6P-3.5X2.65X0.94MM
NFC1, NFC2: TEST-POINT'4080'; TP-80X40MIL
Q1: PMOS_1.00.60.35MM; PMOS_1.0_0.6_0.35MM
R1, R2: 5.1k; R0201
R3, R5, R7: 2.2k; R0201
R4, R13, R14, R15, R20: 10k; R0201
R9: 100k; R0201
R10, R11: 33R; R0201
R12, R18: 2.7k; R0201
R16: 1M_1%; R0201
R17: 510k_1%; R0201
RGB6: RGB; 4P1010
TP1, TP2, TP3, TP5: TEST-POINT'4545'; TP-D45MIL
U1: NRF52840_QF; AQFN50P700X700X85_HS-74N
U2: BQ25100; BQ25101_DSBGA_6_BQ25101
U3: LSM6DS3TR-C; LGA14-0.5-2.5X3X0.86MM
U6: 3.3V; X2SON-4
U7: DNP; USON2X3_8
USB1: USB2.0-TYPE-C
X1: 32.768KHz; X2-SMD-L1.6X1.0X0.5MM
X2: 32MHz; 4P1612

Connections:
3V3: C3.2, C6.2, C29.2, C39.1, C41.2, J1.5, J1.17 (5), R5.1, R13.1, RGB6.+, U1.A22 (VDD@A22), U1.AD14 (VDD@AD14), U1.AD23 (VDD@AD23), U1.B1 (VDD@B1), U1.W1 (VDD@W1), U1.Y2 (VDDH@Y2), U6.1 (OUT), U7.8 (VCC)
6D_INT1: U1.T2 (P0.11@T2), U3.4 (INT1)
6D_PWR: C1.2, R14.1, R15.1, U1.P2 (P1.08@P2), U3.5 (VDDIO), U3.8 (VDD), U3.12 (CS)
/CE: R20.1, U2.B1 (TS)
DEC4-6: C34.1, C42.1, L3.2, U1.B5 (DEC4@B5), U1.E24 (DEC6@E24)
GND: ANT1.2 (GND), C1.1, C2.1, C3.1, C4.2, C5.2, C6.1, C7.1, C8.1, C9.1, C10.2, C11.1, C22.1, C24.1, C25.1, C29.1, C30.2, C31.2, C32.2, C33.2, C34.2, C35.2, C36.1, C37.1, C39.2, C40.2, C41.1, C42.2, GND0.1, J1.6, J1.18 (6), K1.2 (B0), K1.4 (B1), MIC1.4 (GND@1), MIC1.5 (L/R), MIC1.6 (GND@2), R1.2, R2.1, R9.1, R18.2, R20.2, TP1.T, U1.B7 (VSS@B7), U1.F23 (VSS_PA@F23), U1.G74 (VSS_PAD), U2.C2 (VSS), U3.1 (SDO/DA0), U3.2 (SDX), U3.3 (SCX), U3.6 (GND@1), U3.7 (GND@2), U6.2 (GND), U6.T (GND), U7.4 (GND), U7.PAD (T), USB1.A1_B12 (A1/B12/GND), USB1.B1_A12 (B1/A12/GND), USB1.S1, USB1.S2, USB1.S3, USB1.S4, USB1.S5 (S1), USB1.S6 (S2), X2.2 (1), X2.4 (3)
INTERNAL_I2C_SCL: R14.2, U1.H2 (P0.27@H2), U3.13 (SCL)
INTERNAL_I2C_SDA: R15.2, U1.M2 (P0.07@M2), U3.14 (SDA)
unnamed: R1.1, USB1.A5 (A5/CC1)
unnamed: R2.2, USB1.B5 (B5/CC2)
unnamed: C2.2, U1.D2 (P0.00/XL1@D2), X1.2
unnamed: C7.2, U1.F2 (P0.01/XL2@F2), X1.1
unnamed: R7.1, RGB6.R-
unnamed: R4.1, RGB6.G-
unnamed: R10.2, U1.AD4 (D-@AD4)
unnamed: R11.2, U1.AD6 (D+@AD6)
unnamed: R3.1, RGB6.B-
unnamed: CHG0.+, R5.2
unnamed: ANT1.3, C10.1
unnamed: R12.1, R18.1, U2.B2 (ISET)
unnamed: C22.2, U1.AC5 (DECUSB@AC5)
unnamed: C24.2, U1.C1 (DEC1@C1)
unnamed: C31.1, U1.N24 (DEC5@N24)
unnamed: C33.1, U1.B24 (XC1@B24), X2.1 (2)
unnamed: C32.1, U1.A23 (XC2@A23), X2.3 (4)
unnamed: C35.1, U1.D23 (DEC3@D23)
unnamed: C36.2, C38.1, U1.H23 (ANT@H23)
unnamed: ANT1.1 (S), C37.2, C38.2
unnamed: C40.1, U1.A18 (DEC2@A18)
unnamed: L3.1, U1.B3 (DCC@B3)
P0.02_AIN0_LOW_A0_D0: J2.1, J2.13 (1), U1.A12 (P0.02/AIN0@A12)
P0.03_AIN1_LOW_A1_D1: J2.2, J2.14 (2), U1.B13 (P0.03/AIN1@B13)
P0.04_AIN2_A4_D4: J2.5, J2.17 (5), U1.J1 (P0.04/AIN2@J1)
P0.05_AIN3_A5_D5: J2.6, J2.18 (6), U1.K2 (P0.05/AIN3@K2)
P0.06_USER_BLUE: R3.2, U1.L1 (P0.06@L1)
P0.09/NFC1: NFC1.1, U1.L24 (P0.09/NFC1@L24)
P0.10/NFC2: NFC2.1, U1.J24 (P0.10/NFC2@J24)
P0.13_HICHG: R12.2, U1.AD8 (P0.13@AD8)
P0.14_~READ_BAT: R17.2, U1.AC9 (P0.14@AC9)
P0.16_PDM_DATA: MIC1.3 (DATA), U1.AC11 (P0.16@AC11)
P0.17_~CHG: CHG0.-, U1.AD12 (P0.17@AD12), U2.C1 (PRETERM)
P0.20_QSPI_SIO_0: U1.AD16 (P0.20@AD16), U7.5 (DI)
P0.21_QSPI_SCK: C11.2, U1.AC17 (P0.21@AC17), U7.6 (CLK)
P0.22_QSPI_SIO_2: U1.AD18 (P0.22@AD18), U7.3 (~WP)
P0.23_QSPI_SIO_3: U1.AC19 (P0.23@AC19), U7.7 (~HOLD)
P0.24_QSPI_SIO_1: U1.AD20 (P0.24@AD20), U7.2 (DO)
P0.25_QSPI_CSN: U1.AC21 (P0.25@AC21), U7.1 (~CS)
P0.26_USER_RED: R7.2, U1.G1 (P0.26@G1)
P0.28_AIN4_LOW_A2_D2: J2.3, J2.15 (3), U1.B11 (P0.28/AIN4@B11)
P0.29_AIN5_LOW_A3_D3: J2.4, J2.16 (4), U1.A10 (P0.29/AIN5@A10)
P0.30_USER_GREEN: R4.2, U1.B9 (P0.30/AIN6@B9)
P0.31_AIN7_BAT: R16.2, R17.1, U1.A8 (P0.31/AIN7@A8)
P1.00_PDM_CLK: MIC1.2 (CLK), U1.AD22 (P1.00@AD22)
P1.10_MIC_PWR: C8.2, MIC1.1 (VDD), U1.A20 (P1.10@A20)
P1.11_TX_D6: J2.7, J2.19 (7), U1.B19 (P1.11@B19)
P1.12_RX_D7: J1.1, J1.13 (1), U1.B17 (P1.12@B17)
P1.13_SCK_D8: J1.2, J1.14 (2), U1.A16 (P1.13@A16)
P1.14_MISO_D9: J1.3, J1.15 (3), U1.B15 (P1.14@B15)
P1.15_MOSI_D10: J1.4, J1.16 (4), U1.A14 (P1.15@A14)
PWR_LED: U1.R24 (P1.06@R24)
RESET: C5.1, K1.1 (A0), K1.3 (A1), R13.2, TP2.T, U1.AC13 (P0.18/RESET@AC13)
SWDCLK: TP3.T, U1.AA24 (SWDCLK@AA24)
SWDIO: TP5.T, U1.AC24 (SWDIO@AC24)
USB_D+: R11.1, USB1.A6 (A6/DP1), USB1.B6 (B6/DP2)
USB_D-: R10.1, USB1.A7 (A7/DN1), USB1.B7 (B7/DN2)
VBAT: BAT0.1, C30.1, Q1.1 (D), R16.1, U2.A1 (OUT)
VBUS: C9.2, C25.2, D1.+, J1.7, J1.19 (7), Q1.2 (G), R9.2, U1.AD2 (VBUS@AD2), U2.A2 (IN), USB1.A4_B9 (A4/B9/VBUS), USB1.B4_A9 (B4/A9/VBUS)
VIN: C4.1, D1.-, Q1.3 (S), U6.3 (EN), U6.4 (IN)

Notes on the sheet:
Linus.Liao
2.Change C32,C33 to 15pF
zhihuai.Zhou
Initail Version
the TS and VSS.
NTC:
2021.2.2
Set P0.14 to output Sink only to enable BAT voltage read;
v1.0
2.Add C11 to to resolve the issue of data corruption during Flash read operations.
1.Change 32M Crystal
Disable Temp sense function,
2025.6.20
1.Remove R8
use fixed 10k resistor between
2024.3.19

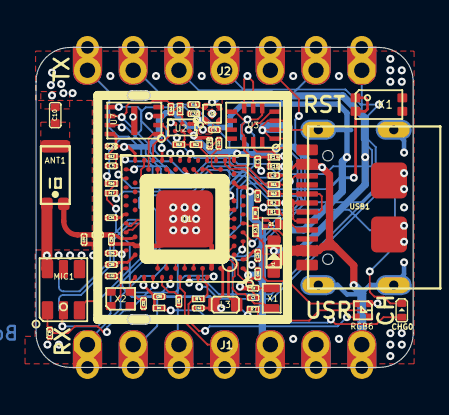
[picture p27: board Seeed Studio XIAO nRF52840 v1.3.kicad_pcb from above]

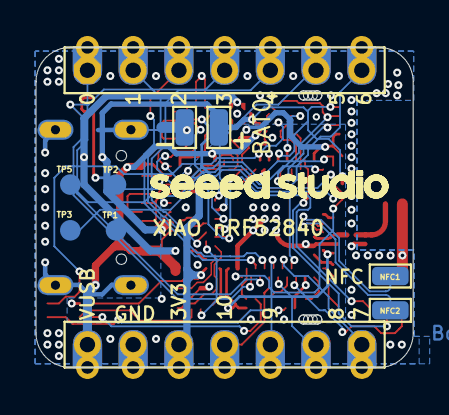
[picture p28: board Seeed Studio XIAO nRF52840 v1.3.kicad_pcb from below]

Board: 2 copper layers, 21.0 x 17.8 mm, 80 parts (9 on the bottom side), 67 nets.

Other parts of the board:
U$14: LOGO-SEEED-NEW-1_3X13MM
UNK_HOLE_0: dummyfp0
UNK_HOLE_1: dummyfp1
UNK_HOLE_2: dummyfp2
UNK_HOLE_3: dummyfp3
UNK_HOLE_4: dummyfp4
UNK_HOLE_5: dummyfp5
UNK_HOLE_6: dummyfp6
UNK_HOLE_7: dummyfp7

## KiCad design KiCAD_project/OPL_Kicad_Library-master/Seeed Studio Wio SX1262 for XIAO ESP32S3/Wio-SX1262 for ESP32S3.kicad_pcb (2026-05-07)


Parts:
C1: 100nF; C0402; Voltage Rating 16V,X7R; MPN CC0402KRX7R7BB104
D1: Green; LED-0603; MPN 19-217/G7C-AN1P2/3T
J1, J2: Header 1x7 2.54mm; H7-2.54; Part Type Header
J3: 30pin; BTB2X15-FEMALE-8.6X2.94X3.9MM; Rating DC0.3A; MPN BTB SCOKET P0.40
K1: TS-1185E; BUTTON2P_3_9X3X2MM; MPN TS-1185E
R1, R3: 10K; R0402; Power Rating 5%; MPN RC0402JR-0710KL
R2: 330R; R0402; Power Rating 1%; MPN RC0402FR-07330RL
R4, R5, R6, R7: 47R; R0402; Power Rating 1%; MPN RC0201FR-0745RL
TP1: Test Point; TP-D3_5c2_2mm; Part Type Test Point
U1: Wio-SX1262; MODULE12P-1.27-11X11.6MM; MPN Wio-SX1262

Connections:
+3V3: C1.1, J2.3, J3.23, J3.25, R1.2, R3.2, U1.8 (VCC)
GND: C1.2, J2.2, J3.2, J3.3, J3.5, J3.27, K1.1, R2.1, U1.7 (GND1), U1.10 (GND2)
GPIO14: J3.20
GPIO15: J3.22
GPIO16: J3.24
GPIO17: J3.26
GPIO18: J3.28
GPIO21: J3.29, K1.2, R3.1
GPIO47: J3.17
GPIO48: D1.1 (+), J3.19
LORA_BUSY: J1.2, J3.11, U1.11 (BUSY)
LORA_DIO1: J1.1, J3.13, U1.12 (DIO1)
LORA_RF_SW1: J1.5, J3.15, U1.1 (RF_SW1)
LORA_RST: J1.3, J3.7, R1.1, U1.5 (RST)
LORA_SPI_MISO: J2.5, J3.8, R4.1
LORA_SPI_MOSI: J2.4, J3.10, R5.1
LORA_SPI_NSS: J1.4, J3.9, R7.1
LORA_SPI_SCK: J2.6, J3.6, R6.1
unnamed: D1.2 (-), R2.2
unnamed: R4.2, U1.2 (MISO)
unnamed: R5.2, U1.3 (MOSI)
unnamed: R7.2, U1.6 (NSS)
unnamed: R6.2, U1.4 (SCK)
VIN: J2.1, J3.1, J3.30



Board: 2 copper layers, 17.8 x 21.4 mm, 15 parts (5 on the bottom side), 18 nets.

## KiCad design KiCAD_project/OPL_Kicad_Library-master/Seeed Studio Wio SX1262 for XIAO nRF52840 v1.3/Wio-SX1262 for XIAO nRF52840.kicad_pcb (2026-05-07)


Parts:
C1: 100nF; C0402; Voltage Rating 16V,X7R; MPN CC0402KRX7R7BB104
J1, J2: Header 1x7 2.54mm; H7-2.54; Part Type Header
K1: TS-1188E 6C81; SW4-SMD-7.0X3.5X3.5MM-90D; MPN TS-1188E 6C81; not fitted
R1: 10K; R0402; Power Rating 5%; MPN RC0402JR-0710KL
R2: 10K; R0402; Power Rating 5%; MPN RC0402JR-0710KL; not fitted
R3, R4, R5, R6: 22R; R0402; Power Rating 1%; MPN RC0402FR-0722RL
U1: Wio-SX1262; MODULE12P-1.27-11X11.6MM; MPN Wio-SX1262

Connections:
+3V3: C1.1, J2.3, R1.2, R2.2, U1.8 (VCC)
/D0: J1.1, K1.2, R2.1
/LORA_BUSY: J1.4, U1.11 (BUSY)
/LORA_DIO1: J1.2, U1.12 (DIO1)
/LORA_RF_SW1: J1.6, U1.1 (RF_SW1)
/LORA_RST: J1.3, R1.1, U1.5 (RST)
/LORA_SPI_MISO: J2.5, R4.1
/LORA_SPI_MOSI: J2.4, R5.1
/LORA_SPI_NSS: J1.5, R3.1
/LORA_SPI_SCK: J2.6, R6.1
GND: C1.2, J2.2, K1.1, K1.3 (S1), K1.4 (S2), U1.7 (GND1), U1.10 (GND2)
unnamed: R4.2, U1.2 (MISO)
unnamed: R5.2, U1.3 (MOSI)
unnamed: R3.2, U1.6 (NSS)
unnamed: R6.2, U1.4 (SCK)
VIN: J2.1


Board: 2 copper layers, 17.8 x 21.4 mm, 11 parts (0 on the bottom side), 15 nets.

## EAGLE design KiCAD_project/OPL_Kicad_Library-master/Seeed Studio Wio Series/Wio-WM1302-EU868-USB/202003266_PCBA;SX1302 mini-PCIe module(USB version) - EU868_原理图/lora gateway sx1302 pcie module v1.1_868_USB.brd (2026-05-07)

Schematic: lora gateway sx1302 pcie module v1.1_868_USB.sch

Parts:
ANT1: U.FL-R-SMT-1(10); U-FL3P-SMD-2.6X2.6X1.0MM
ANT2: DNP; U-FL3P-SMD-2.6X2.6X1.0MM
C1, C12, C15, C19, C23, C25, C26, C29, C32, C41, C43, C45, C65, C67, C80, C83, C86, C88: 100nF; C0402
C2, C75: 2.2pF; C0402
C3, C92: 10uF; C0603
C4, C8, C11, C16, C17, C18, C64: 56pF; C0402
C5, C6, C9, C10: 3.6pF; C0402
C7, C91: 5.6pF; C0402
C13, C20, C21, C24, C28, C35, C39, C40, C42, C44, C47, C48, C76, C87, C89: 1uF; C0402
C14, C38, C57, C66, C81, C84: 10pF; C0402
C22, C27, C33: 10uF; C0603@1
C30, C56, C74, C77, C78, C79: DNP; C0402
C31: DNP; C0603@1
C34, C46, C63: 470nF; C0402
C36: 47nF; C0402
C37: 47pF; C0402
C49: 4.7uF; C0603
C50, C62, C85: 10nF; C0402
C51: 1nF; C0402
C52, C55: 100pF; C0402
C53, C60, C61: 3.3pF; C0402
C54: 39pF; C0402
C58: 1.3pF; C0402
C59, C68, C73: 1.8pF; C0402
C69, C70, C71, C72: 10uF; C0805
C82: 2.7pF; C0402
C90: 2.2uF; C0603
D1, D4: Green; LED-0402
D2: Red; LED-0402
D3: Blue; LED-0402
D5: LXES15AAA1-153; ESD-0402
D6: DNP; ESD-0402
D7: BAT54XV2T1G; SOD-523
FB1: BLM15PD121SN1D; F0402
J1: DNP; PCIE52P-0.8-50.95X30MM
L1: LQP15MN1N2B02D; L0402
L2: LQW15AN6N8G00D; L0402
L4: 0R; F0603
L5: LQH44PN1R0NP0L; L4.4X3.0MM
L6, L14, L20: MLZ2012M150WT; L0805
L7, L15, L18, L21: DNP; L0402
L8: LQW15AN3N0B00; L0402
L9: LQW15AN47NJ00D; L0402
L10: LQW15AN2N5B00D; L0402
L11: LQW15AN4N7C00D; L0402
L12, L13: LQW15AN12NG00D; L0402
L16: LQW15AN7N5G00D; L0402
L17, L24: LQW15AN5N6C10D; L0402
L22: LQW15AN15NG00D; L0402
Q8: CJ2101; SOT-323
Q10: CJ2102; SOT-323
R1, R4, R33, R34, R38, R42, R57, R65, R71: 10k; R0402
R2, R7: 0R; R0603
R3, R8, R11, R12, R43, R44, R46, R49, R51, R55, R56, R59, R60, R61, R62, R63, R67, R70, R72, R73, R74, R75, R76, R81: DNP; R0402
R5, R10, R14, R15, R16, R39, R40, R41: 100R; R0402
R6, R9, R37: 220R; R0402
R13, R35, R52: DNP; R0603
R17, R18, R19, R20, R21, R22, R23, R24, R25, R26, R27, R28, R29, R36, R45, R48, R50, R53, R54, R69, R77: 0R; R0402
R30, R31, R32: 680R; R0402
R47, R79: 1k; R0402
R58, R68: 4.7k; R0402
R64, R66: 22R; R0402
R78, R82: 100k; R0402
R80: 10R; R0402
R83, R87: 200k_1%; R0402
S1, S2, S3, S4, S5, S6: 323030226; SHIELD_CLIP
TP1, TP2, TP3, TP4, TP5, TP6, TP7, TP8, TP9, TP10, TP14: TEST-POINT-35; TP_3535
TP15: TEST-POINT'4545'; TP-D45MIL
U1: SX1302IMLTRT; QFN68-0.35-7X7X0.75MM
U2, U8, U10: HDF866A3-S6; FILTER6P-1.1-3X3X1.3MM
U3, U4: DNP; SOT-23-5
U5, U7: SX1250IMLTRT; QFN24G-0.5-4X4MM
U6: MP2161GJ; TSOT23-8
U9: SKY66420-11; MODULE16P-0.5-3X3X0.75MM
U11: SX1262IMLTRT; QFN24G-0.5-4X4MM
U12: STM32L412K8U6; UFQFPN32-0.5-5X5MM
U13: STTS751; UDFN-6L
X1: DSB221SDN; X4-SMD-2.5X2.0X1.0MM
X3: 32.768kHz; X2-SMD-3.2X1.5X0.55MM

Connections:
32MHZ: R6.2, R9.2, R37.2, X1.3 (OUT)
1302_CS: R33.2, R43.1, U1.1 (HOST_CSN), U12.10 (PA4)
1302_RESET: C1.2, D7.-, R1.2, U1.7 (RESET), U12.8 (PA2)
1302_RESET_HOST: D7.+, R59.1
CONFIG_OK: R31.1, U1.66 (GPIO0)
DM: J1.36, R66.1
DP: J1.38, R64.1
FEM_CS: R14.2, R34.1, U1.10 (RADIO_CTRL0), U3.3 (CE)
FEM_PA_ON: R15.2, U1.16 (RADIO_CTRL4)
GND: ANT1.GND1, ANT1.GND2, ANT2.GND1, ANT2.GND2, C2.1, C3.1, C5.1, C7.1, C9.1, C12.1, C13.1, C15.1, C16.1, C17.1, C18.1, C19.1, C20.1, C21.1, C22.1, C23.1, C24.1, C25.1, C26.1, C27.1, C28.1, C29.1, C30.1, C31.1, C32.1, C33.1, C34.1, C35.1, C36.1, C37.1, C39.1, C40.1, C41.1, C42.1, C43.1, C44.1, C45.1, C46.1, C47.1, C48.1, C49.1, C50.1, C51.1, C52.1, C55.1, C56.1, C57.1, C58.1, C60.2, C61.2, C62.1, C63.2, C65.2, C67.2, C69.1, C70.1, C71.1, C72.1, C73.2, C74.2, C76.1, C77.2, C78.2, C80.1, C81.2, C82.2, C83.1, C84.2, C85.1, C86.1, C87.1, C88.1, C89.1, C90.1, C92.1, D1.-, D2.-, D3.-, D4.-, D5.1, D6.1, J1.4 (GND), J1.9 (GND), J1.15 (GND), J1.18 (GND), J1.21 (GND), J1.26 (GND), J1.27 (GND), J1.29 (GND), J1.34 (GND), J1.35 (GND), J1.37 (GND), J1.40 (GND), J1.43 (GND), J1.50 (GND), J1.S1 (GND), J1.S2 (GND), Q10.2 (S), R1.1, R4.1, R11.1, R12.1, R17.2, R53.1, R53.2, R54.1, R54.2, R55.1, R55.2, R57.2, R73.1, R74.1, R74.2, R87.1, S1.S1, S1.S2, S1.S3, S1.S4, S1.S5, S2.S1, S2.S2, S2.S3, S2.S4, S2.S5, S3.S1, S3.S2, S3.S3, S3.S4, S3.S5, S4.S1, S4.S2, S4.S3, S4.S4, S4.S5, S5.S1, S5.S2, S5.S3, S5.S4, S5.S5, S6.S1, S6.S2, S6.S3, S6.S4, S6.S5, TP3.T, U1.6 (GND), U1.9 (GND), U1.15 (GND), U1.24 (GND), U1.25 (GND), U1.39 (GND), U1.46 (GND), U1.55 (GND), U1.62 (GND), U1.69 (GND), U2.1 (GND), U2.3 (GND), U2.4 (GND), U2.6 (GND), U3.2 (VSS), U4.2 (VSS), U5.7 (GND), U5.20 (GND), U5.PAD, U6.4 (PGND), U6.6 (AGND), U7.7 (GND), U7.20 (GND), U7.PAD, U8.1 (GND), U8.3 (GND), U8.4 (GND), U8.6 (GND), U9.10 (GND), U9.12 (GND), U9.17 (EPAD), U10.1 (GND), U10.3 (GND), U10.4 (GND), U10.6 (GND), U11.2 (GND), U11.5 (GND), U11.8 (GND), U11.20 (GND), U11.PAD, U12.16 (VSS), U12.32 (VSS), U12.PAD, U13.4 (ADDR/!THERM), U13.5 (GND), X1.2 (GND)
HOST_CS0: J1.51, R43.2
HOST_CS1: J1.25, R51.2
HOST_IO1: J1.33, R61.2
HOST_IO2: J1.31, R63.2
HOST_IO3: J1.23
HOST_IO4: J1.8, R67.2
HOST_IO5: J1.10, R60.2
HOST_IO6: J1.12
HOST_MISO: R39.1, R44.2
HOST_MOSI: J1.49, R46.2
HOST_RST: J1.22, R59.2, R77.2
HOST_SCK: J1.45, R49.2
I2C_SCL: R68.2, R76.1, R81.1, U12.29 (PB6), U13.1 (SCL)
I2C_SDA: R58.2, R70.1, R75.1, U12.30 (PB7), U13.6 (SDA)
MCU_RESET: C85.2, R71.2, R77.1, TP5.T, U12.4 (NRST)
MISO: R44.1, R45.1, U1.2 (HOST_MISO), U11.16 (MISO)
MISO_A: U1.42 (RADIO_A_MISO), U5.16 (MISO)
MISO_B: U1.33 (RADIO_B_MISO), U7.16 (MISO)
MOSI: R5.2, R40.2, R46.1, R48.1
MOSI_A: U1.67 (RADIO_A_MOSI), U5.17 (MOSI)
MOSI_B: U1.19 (RADIO_B_MOSI), U7.17 (MOSI)
unnamed: C11.2, U9.2 (RX)
unnamed: TP15.T, U6.1 (PG)
unnamed: C8.1, R11.2, R52.2, U8.5 (OUT)
unnamed: C2.2, L11.2, R52.1, U8.2 (IN)
unnamed: C11.1, R13.2, U2.2 (IN)
unnamed: C4.2, U9.1 (TX)
unnamed: C68.1, C74.1, C75.2
unnamed: C65.1, L18.2, R36.2, U11.1 (VDD_IN)
unnamed: C66.2, R37.1
unnamed: L5.1, U6.3 (SW)
unnamed: R83.1, R87.2, U6.7 (FB)
unnamed: R3.1, R4.2, X1.1 (ENABLE)
unnamed: C14.1, U5.3 (XTA)
unnamed: C62.2, L4.1, R3.2, X1.4 (VDD)
unnamed: R5.1, U1.3 (HOST_MOSI)
unnamed: D4.+, R47.2
unnamed: R10.1, U1.4 (HOST_SCK)
unnamed: R82.2, U6.8 (EN)
unnamed: R8.1, U4.3 (CE)
unnamed: C14.2, R6.1
unnamed: L6.2, U5.8 (DCC_SW)
unnamed: C34.2, L6.1, L7.2, U5.6 (VREG)
unnamed: C64.1, C82.1, L24.2
unnamed: R19.1, U1.34 (RADIO_B_CLK_I)
unnamed: C16.2, R14.1, U9.4 (CSD)
unnamed: C38.1, U7.3 (XTA)
unnamed: C36.2, C37.2, L9.2, U5.1 (VR_PA)
unnamed: C38.2, R9.1
unnamed: L14.2, U7.8 (DCC_SW)
unnamed: C46.2, L14.1, L15.2, U7.6 (VREG)
unnamed: C54.2, L11.1
unnamed: C7.2, C53.2, C54.1, L10.2
unnamed: C4.1, C8.2, R12.2
unnamed: C17.2, R15.1, U9.5 (CPS)
unnamed: C18.2, R16.1, U9.6 (CTX)
unnamed: R17.1, U1.20 (SP_VALID)
unnamed: R18.1, U1.32 (RADIO_B_IQ3)
unnamed: R20.1, U1.35 (RADIO_B_IQ0)
unnamed: R24.1, U1.41 (RADIO_A_IQ3)
unnamed: R21.1, U1.36 (RADIO_B_IQ1)
unnamed: R22.1, U1.37 (RADIO_B_IQ4)
unnamed: R23.1, U1.38 (RADIO_B_IQ2)
unnamed: R25.1, U1.43 (RADIO_A_CLK_I)
unnamed: R26.1, U1.44 (RADIO_A_IQ0)
unnamed: R27.1, U1.45 (RADIO_A_IQ1)
unnamed: R28.1, U1.48 (RADIO_A_IQ4)
unnamed: R29.1, U1.49 (RADIO_A_IQ2)
unnamed: D3.+, R32.2
unnamed: D2.+, R31.2
unnamed: D1.+, R30.2
unnamed: Q8.1 (G), Q10.3 (D), R78.2
unnamed: C1.1, R80.1
unnamed: L1.1, U9.16 (VCC1)
unnamed: L2.1, L8.1, U9.13 (PA_OUT)
unnamed: C56.2, C57.2, L8.2, L16.1
unnamed: C58.2, L16.2, U9.11 (TX_IN)
unnamed: C59.2, C60.1, L17.1, U9.9 (ANT)
unnamed: C61.1, C91.1, L17.2, L24.1
unnamed: C66.1, U11.3 (XTA)
unnamed: ANT1.D, C64.2, D5.2
unnamed: R35.2, R62.1, R69.2, U10.2 (IN)
unnamed: C63.1, L18.1, L20.1, U11.7 (VREG)
unnamed: R35.1, U9.7 (LNA_IN), U10.5 (OUT)
unnamed: L20.2, U11.9 (DCC_SW)
unnamed: J1.47, R39.2
unnamed: R40.1, U11.17 (MOSI)
unnamed: R41.1, U11.18 (SCK)
unnamed: C6.1, C10.1, C75.1, R13.1, U2.5 (OUT)
unnamed: R69.1, U9.8 (RX_FLT)
unnamed: C78.1, C79.1, L21.2
unnamed: ANT2.D, C79.2, D6.2
unnamed: C59.1, C91.2
unnamed: C77.1, L21.1, R62.2
unnamed: R65.2, U13.2 (!EVENT)
unnamed: C52.2, FB1.1, L1.2, U9.15 (VCC0)
unnamed: R64.2, U12.22 (PA12)
unnamed: R66.2, U12.21 (PA11)
unnamed: C92.2, Q10.1 (G), R79.2
unnamed: R56.2, R57.1, U12.31 (BOOT0)
unnamed: R72.2, R73.2, U12.6 (PA0-CLK_IN)
unnamed: C81.1, U12.2 (PC14-OSC32_IN), X3.2
unnamed: C84.1, U12.3 (PC15-OSC32_OUT), X3.1
unnamed: J1.14, R76.2
unnamed: J1.16, R70.2
unnamed: J1.30, R81.2
unnamed: J1.32, R75.2
PPS: J1.19, TP2.T, U1.8 (PPS), U12.27 (PB4)
RADIO_A_CLK_32M: R25.2, R72.1, U5.14 (BUSY)
RADIO_A_CLK_O: R28.2, U5.11 (DIO5)
RADIO_A_CSN: U1.68 (RADIO_A_CSN), U5.19 (NSS)
RADIO_A_IQ_0: R26.2, U5.13 (DIO1)
RADIO_A_IQ_1: R27.2, U5.12 (DIO2)
RADIO_A_IQ_2: R29.2, U5.5 (DIO3)
RADIO_A_IQ_3: R24.2, U5.21 (DIO4)
RADIO_A_RESET: U1.13 (RADIO_CTRL3), U5.15 (NRESET)
RADIO_A_RFIN: C6.2, L12.2, U5.23 (RFI_N)
RADIO_A_RFIP: C5.2, L12.1, U5.22 (RFI_P)
RADIO_B_CLK_32M: R19.2, U7.14 (BUSY)
RADIO_B_CLK_O: R22.2, U7.11 (DIO5)
RADIO_B_CSN: U1.18 (RADIO_B_CSN), U7.19 (NSS)
RADIO_B_IQ0: R20.2, U7.13 (DIO1)
RADIO_B_IQ_1: R21.2, U7.12 (DIO2)
RADIO_B_IQ_2: R23.2, U7.5 (DIO3)
RADIO_B_IQ_3: R18.2, U7.21 (DIO4)
RADIO_B_RESET: U1.28 (RADIO_CTRL9), U7.15 (NRESET)
RADIO_B_RFIN: C10.2, L13.2, U7.23 (RFI_N)
RADIO_B_RFIP: C9.2, L13.1, U7.22 (RFI_P)
RFO: C53.1, L9.1, L10.1, U5.24 (RFO)
RX_ON: R32.1, U1.59 (GPIO4)
SCK: R10.2, R41.2, R49.1, R50.1
SCK_A: U1.65 (RADIO_A_SCK), U5.18 (SCK)
SCK_B: U1.21 (RADIO_B_SCK), U7.18 (SCK)
STM32_MISO: R45.2, U12.12 (PA6)
STM32_MOSI: R48.2, U12.13 (PA7)
STM32_SCK: R50.2, U12.11 (PA5)
SWCLK: TP7.T, U12.24 (PA14)
SWDIO: TP8.T, U12.23 (PA13)
SX1261_BUSY: R67.1, U11.14 (BUSY), U12.9 (PA3)
SX1261_CS: R42.1, R51.1, U11.19 (NSS), U12.14 (PB0)
SX1261_IO1: R61.1, U1.54 (GPIO7), U11.13 (DIO1), U12.15 (PB1)
SX1261_IO2: R63.1, U11.12 (DIO2)
SX1261_IO3: TP9.T, U11.6 (DIO3)
SX1261_RFIN: C68.2, L22.2, U11.22 (RFI_N)
SX1261_RFIP: C73.1, L22.1, U11.21 (RFI_P)
SX1261_RST: R38.1, R60.1, U11.15 (NRESET), U12.18 (PA8)
SX1302_GPIO8: U1.53 (GPIO8), U12.26 (PB3)
TX_ON: R30.1, U1.63 (GPIO2)
TX_RX_SW: R16.2, U1.12 (RADIO_CTRL2)
VCCIO: C3.2, C19.2, C20.2, C25.2, C28.2, C41.2, C42.2, C45.2, C47.2, C76.2, C80.2, C83.2, C86.2, C87.2, C88.2, C89.2, C90.2, Q8.3 (D), R33.1, R34.2, R56.1, R58.1, R65.1, R68.1, R71.1, R80.2, TP1.T, U1.14 (VCC_IO), U1.30 (VCC_IO), U1.47 (VCC_IO), U1.61 (VCC_IO), U12.1 (VDD), U12.5 (VDDA), U12.17 (VDD), U13.3 (VDD)
VCC_1V2: C12.2, C13.2, C23.2, C24.2, C29.2, C40.2, C43.2, C44.2, C71.2, C72.2, L5.2, R79.1, R83.2, TP14.T, U1.5 (VCC_CORE), U1.23 (VCC_CORE), U1.40 (VCC_CORE), U1.56 (VCC_CORE), U6.5 (OUT)
VCC_FEM: C26.2, C27.2, C49.2, C50.2, C51.2, C55.2, FB1.2, L2.2, R2.2, TP6.T, U3.5 (VOUT)
VCC_RADIO: C21.2, C32.2, C33.2, C35.2, C39.2, C48.2, C67.1, L4.2, L7.1, L15.1, R7.2, R36.1, R38.2, R42.2, TP10.T, U4.5 (VOUT), U5.2 (VDD_IN), U5.9 (VBAT_RF), U5.10 (VBAT_DIO), U7.2 (VDD_IN), U7.9 (VBAT_RF), U7.10 (VBAT_DIO), U11.10 (VBAT), U11.11 (VBAT_IO)
VIN: C15.2, C22.2, C30.2, C31.2, C69.2, C70.2, J1.2 (3V3), J1.24 (3V3), J1.39 (3V3), J1.41 (3V3), J1.52 (3V3), Q8.2 (S), R2.1, R7.1, R8.2, R47.1, R78.1, R82.1, TP4.T, U3.1 (VIN), U4.1 (VIN), U6.2 (VIN)

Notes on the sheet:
V1.0
Initial Release
2020/01/02
Vincent
50ohm Impedence
3.3V
300mA
1.2V
500mA
100mA
USB
868
915
SPI
For Power-up delay
V1.1
Add power up delay circuit at VCCIO
Add power up reset circuit for SX1302
Change pins refer to Semtech V3 Schematic
2021/02/18



Board: 4 copper layers, 30.0 x 51.0 mm, 244 parts (68 on the bottom side), 162 nets.

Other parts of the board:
U$45: SEEED-SILK-TNAME-280*268MIL

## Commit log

2026-05-05 github setup
    [KiCAD_project.kicad_pcb, KiCAD_project.kicad_sch]
2026-05-07 day 1
    [1_01 Table of Contents.kicad_sch, 2_02 Block Diagram.kicad_sch, 3_03 Power IN & MCU GPIOs.kicad_sch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]
2026-05-09 added images and BOM into readme.md
    [KiCAD_project-B_Cu.gbr, KiCAD_project-B_Mask.gbr, KiCAD_project-B_Paste.gbr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]
2026-05-16 Added edited PCB and CAD
    [3d_PCB.step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]
2026-05-16 Update README with rendered housing images
2026-06-11 Fixed BOM table
2026-06-13 Update BOM CSV to match README BOM structure and clean links
    [My macroPad-bom.csv]
